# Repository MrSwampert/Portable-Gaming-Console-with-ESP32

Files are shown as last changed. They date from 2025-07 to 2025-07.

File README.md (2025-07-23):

# ArcadESP - The Open-Source Retro Gaming Handheld
Portable Gaming Console with ESP32-WROVER, TFT Display, and MicroSD Storage.

# Summary:

ArcadESP is an open-source, portable, retro video game console. Its main utility is to emulate games from classic consoles (such as the NES) using an ESP32 microcontroller, which is a very cheap and powerful chip. The main goal of the project is to leave it as a development board, which allows programming it for more functions.

# Description:
The circuit is centered on an ESP32-WROVER-IE microcontroller. The main power supply for the system is 3.3V.
The design integrates several key peripherals for operation. It includes a TFT screen for graphics display, managed through multiple GPIO connections of the microcontroller. For user input, the system features a series of buttons, including direction controls (up, down, left, right), action buttons (Start, Select, A, B, L, R), and menu buttons, which connect to a PCF8574 I/O port expander.
Data storage is handled through a MicroSD card slot with push-out functionality, allowing the reading and writing of information. Additionally, the circuit incorporates an auto-reset section for the microcontroller. Test points (TP1, TP2, TP3, TP4) are also included for monitoring key voltages such as V_USB, V_BATT and 3.3V.

# Features:
**Processing Core:** **ESP32-WROVER-IE** module with a dual-core CPU, Wi-Fi, Bluetooth, and integrated PSRAM.

**Connectivity & Power:** **USB-B port** for power and programming via an onboard **CH340 USB-to-UART** controller.

**Power Management:** Includes an **LTC4054** Li-Ion battery charger and an **MIC5219 LDO regulator** for a stable 3.3V supply.

**Audio Subsystem:** Features an I2S Stereo DAC (**UDA1334ATS**), a **PAM8403 Class-D amplifier**, and a **3.5mm audio jack** output.

**User Interface:** **TFT color display** for visual output, accompanied by user input buttons and a status LED.

**External Storage:** **Micro SD card slot** for expandable data and media storage.

**I/O Expansion:** **PCF8574 I/O expander** to provide additional digital pins over the I2C bus.

# Applications: 
-	Retro Emulation Console (Main Application)
-	Portable Media Player
-	IoT Device and Control Tool
-	Development and Learning Platform (All in One)

**Entertainment:** Play classic video games on a device you built yourself.
 
**Education:** It's a fantastic tool for learning about electronics, microcontroller programming (in the Arduino IDE), and how software emulation works.
 
**Personal Project (DIY):** It offers the satisfaction of building a functional gadget from scratch, with a very low cost (less than $20, according to similar projects).

# In Terms of Gaming:

Releases are here **https://github.com/retro-esp32/RetroESP32/releases**

It includes 11, YES eleven emulators.

 - Nintendo Entertainment System (NES)
 - Nintendo Game Boy (GB)
 - Nintendo Game Boy Color (GBC)
 - Sega Master System
 - Sega Game Gear
 - Colecovision
 - Sinclair Zx Spectrum 48k
 - Atari 2600
 - Atari 7800
 - Atari Lynx
 - PC Engine

# Sector Focus:
The project is clearly focused on the maker or DIY sector. The target audience are:
 
**Students and Electronics Hobbyists:** People who want to put their hardware and software knowledge into practice.

**Retro Gaming Enthusiasts:** Nostalgic gamers who would enjoy not only playing, but also building their own console.
 
**Programmers and Developers:** Those interested in developing software for embedded systems and optimizing code for hardware with limited resources. (For example, **PICO-8** is a virtual machine that emulates a video game console. While it is impossible to replicate with **ESP32**, there are alternatives such as **Fake-8**, which is the best open source way to run **PICO-8** games on unsupported platforms).

This is not a product for the end consumer looking for an **“out-of-the-box”** console, but for someone who values the process of creation and customization.

The differential value of ArcadESP is its low cost, the use of the versatile ESP32 and its open-source nature, which invites a community to modify, improve and share their own versions.

# Power Budget:
Power Budget

# Block Diagram:
Block Diagram

# Schematic
Schematic_v1_page-0001

Schematic_v1_page-0002

# 3D Model:




# References:

Pebri, “GitHub - pebri86/esplay_micro_hardware: Micro version of esplay hardware, ESP32 based gaming console,” GitHub. **https://github.com/pebri86/esplay_micro_hardware**

“ESPLay Micro V2,” Handheld ESP32 Game Console | Makerfabs. **https://www.makerfabs.com/esplay-micro-v2.html** 

Pebri, “GitHub - pebri86/esplay-retro-emulation: Retro Emulation Collection for ESPlay Hardware, an ESP32 based game console,” GitHub. **https://github.com/pebri86/esplay-retro-emulation**

Pebri, “GitHub - pebri86/esplay-micro-firmware-collections: Firmware files collections (*.fw) for ESPlay Micro,” GitHub. **https://github.com/pebri86/esplay-micro-firmware-collections**

Jtothebell, “GitHub - jtothebell/fake-08: A Pico-8 player/emulator for console homebrew,” GitHub. **https://github.com/jtothebell/fake-08**

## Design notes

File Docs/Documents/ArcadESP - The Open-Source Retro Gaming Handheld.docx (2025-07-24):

Portable Gaming Console with ESP32-WROVER, TFT Display, and MicroSD Storage

Santiago Galeano Castaño Date: 07/23/2025

Summary

ArcadESP is an open-source, portable, retro video game console. Its main utility is to emulate games from classic consoles (such as the NES) using an ESP32 WROVER IE microcontroller, which is a very cheap and powerful chip. The main goal of the project is to leave it as a development board, which allows programming it for more functions.

3D View Reference:

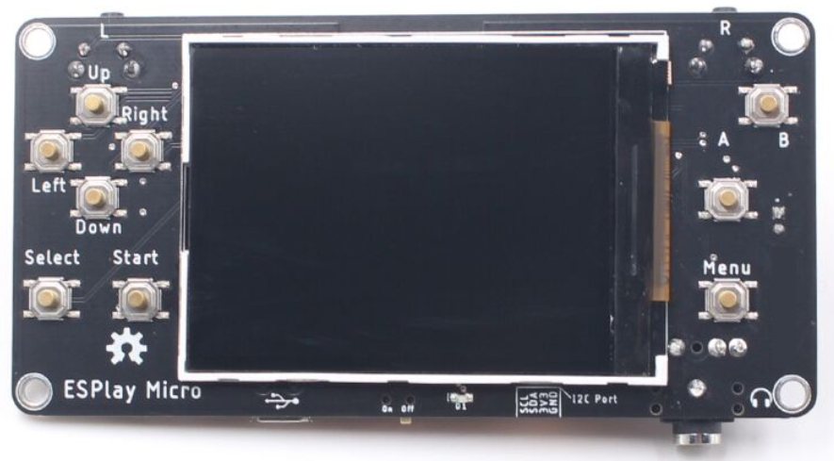
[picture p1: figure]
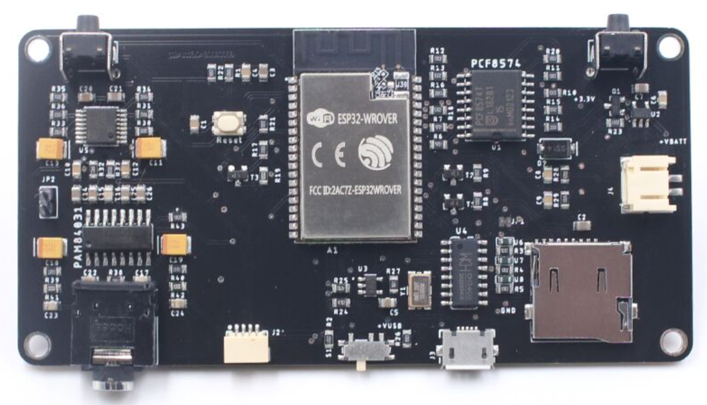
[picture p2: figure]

ArcadESP: The Open-Source Retro Gaming Handheld

Description:

The circuit is centered on an ESP32-WROVER-I microcontroller. The main power supply for the system is 3.3V.

The design integrates several key peripherals for operation. It includes a TFT screen for graphics display, managed through multiple GPIO connections of the microcontroller. For user input, the system features a series of buttons, including direction controls (up, down, left, right), action buttons (Start, Select, A, B), and menu buttons, which connect to a PCF8574 I/O port expander.

Data storage is handled through a MicroSD card slot with push-out functionality, allowing the reading and writing of information. Additionally, the circuit incorporates an auto-reset section for the microcontroller. Test points (TP1, TP2, TP3, TP4) are also included for monitoring key voltages such as V_USB, V_BATT and 3.3V.

Resources:

USB-B (https://lcsc.com/datasheet/lcsc_datasheet_2110151630_XKB-Connection-U-E-M1SS-Y-1_C319151.pdf) | Power and data connector.
LTC4054 (https://lcsc.com/datasheet/lcsc_datasheet_2409272231_NATLINEAR-LN2054Y42AMR_C141406.pdf) | Integrated circuit for battery charging.
MIC5219 3.3v Regulator (https://lcsc.com/datasheet/lcsc_datasheet_2410121904_MICROCHIP-MIC5219-3-3YM5-TR_C29613.pdf) | Regulates and stabilizes the voltage to 3.3V.
ESP32 WROVER-I (https://lcsc.com/datasheet/lcsc_datasheet_2411121102_ESPRESSIF-ESP32-WROVER-IE-N8R8_C701351.pdf) | The main microcontroller (the brain).
CH340 (https://lcsc.com/datasheet/lcsc_datasheet_2506051505_WCH-CH340G_C14267.pdf) | USB to serial converter for programming.
BUTTONS (https://lcsc.com/datasheet/lcsc_datasheet_2304140030_XKB-Connection-TS-1187A-C-C-B_C318889.pdf) | Buttons for user interaction.
PCF8574 I/O Expander (https://lcsc.com/datasheet/lcsc_datasheet_2504101957_HGSEMI-PCF8574T-TR_C2987288.pdf) | Expands input/output pins for the buttons.
TFT Display (https://cdn-shop.adafruit.com/datasheets/ILI9341.pdf) | Screen for visual output.
Micro SD Card (https://lcsc.com/datasheet/lcsc_datasheet_1811082127_Korean-Hroparts-Elec-TF-01A_C91145.pdf) | Module for external storage.
Audio DAC UDA1334ATS (https://www.nxp.com/docs/en/data-sheet/UDA1334ATS.pdf) | Converts digital audio to analog.
Amplifier PAM8403 (https://lcsc.com/datasheet/lcsc_datasheet_2208041800_Slkor-SLKORMICRO-Elec--PAM8403_C5122557.pdf) | Amplifies the audio signal for output.
Jack 3.5mm (https://lcsc.com/datasheet/lcsc_datasheet_2409271733_Korean-Hroparts-Elec-PJ-611-5A_C128983.pdf) | Output connector for headphones or speakers.
LED Blue (https://lcsc.com/datasheet/lcsc_datasheet_2507101606_Hubei-KENTO-Elec-KT-0603B_C2288.pdf) | Visual status indicator light.

Features:

Processing Core: ESP32-WROVER-IE N8R8 module with a dual-core CPU, Wi-Fi, Bluetooth, and integrated PSRAM.

Connectivity & Power: USB-B port for power and programming via an onboard CH340 USB-to-UART controller.

Power Management: Includes an LTC4054 Li-Ion battery charger and an MIC5219 LDO regulator for a stable 3.3V supply.

Audio Subsystem: Features an I2S Stereo DAC (UDA1334ATS), a PAM8403 Class-D amplifier, and a 3.5mm audio jack output.

User Interface: TFT color display for visual output, accompanied by user input buttons and a status LED.

External Storage: Micro SD card slot for expandable data and media storage.

I/O Expansion: PCF8574 I/O expander to provide additional digital pins over the I2C bus.

Applications:

- Retro Emulation Console (Main Application)
- Portable Media Player
- IoT Device and Control Tool
- Development and Learning Platform (All in One)

Power Tree:

▶ Power Source (USB / Battery)

└───▶ Power Systems & Protections

│

├───▶ Charging Circuit (e.g., TP4056)

│ │

│ ├───> Charges the Li-Po Battery (3.7V)

│ │

│ └───> Status LEDs (Charging / Full)

│

└───▶ 3.3V Voltage Regulator

│

└───▶ Main Power Rail (3.3V)

│

├─▶ B. Processing & Storage

│ ├─ Microcontroller (ESP32)

│ └─ Storage (MicroSD Slot)

│

├─▶ C. Output (Display & Audio)

│ ├─ Display (TFT)

│ └─ Audio Output (DAC / Amp)

│

├─▶ D. Inputs & Controls

│ ├─ I/O Expander (I2C)

│ └─ Auto-Reset Circuit

└─▶ E. Debug & Programming

└─ USB to UART Interface

Input Source: Power originates from either a USB connection or a Li-Po Battery.

Charging & Protection: This input power feeds a charging circuit, which manages battery charging and provides a regulated output. This stage also powers the status LEDs.

Main Regulation: Power from the battery or charging circuit is routed to the 3.3V Voltage Regulator. This is the core of the power system, converting the variable battery voltage (typically 3.0V-4.2V) into a stable, constant 3.3V.

Distribution: The 3.3V rail distributes power to all active modules in the device: the microcontroller, display, audio circuitry, SD card slot, I/O expander, and the programming interface.

Power Budget:

The system can be powered by a USB connection or a Li-Po battery. The input power goes through a protection and charging circuit. A central 3.3V voltage regulator then takes this power and supplies a stable 3.3v to all the main components. These components include the ESP32 microcontroller, the TFT display, the audio output, the MicroSD slot, and the input/control circuits.

Typical Use: The device draws 423 mA (2.12 W) from the 5V USB source for normal operation.

Maximum Use: Under heavy load (like using Wi-Fi), the draw spikes to 1.11 A (5.55 W) from the 5V USB source.

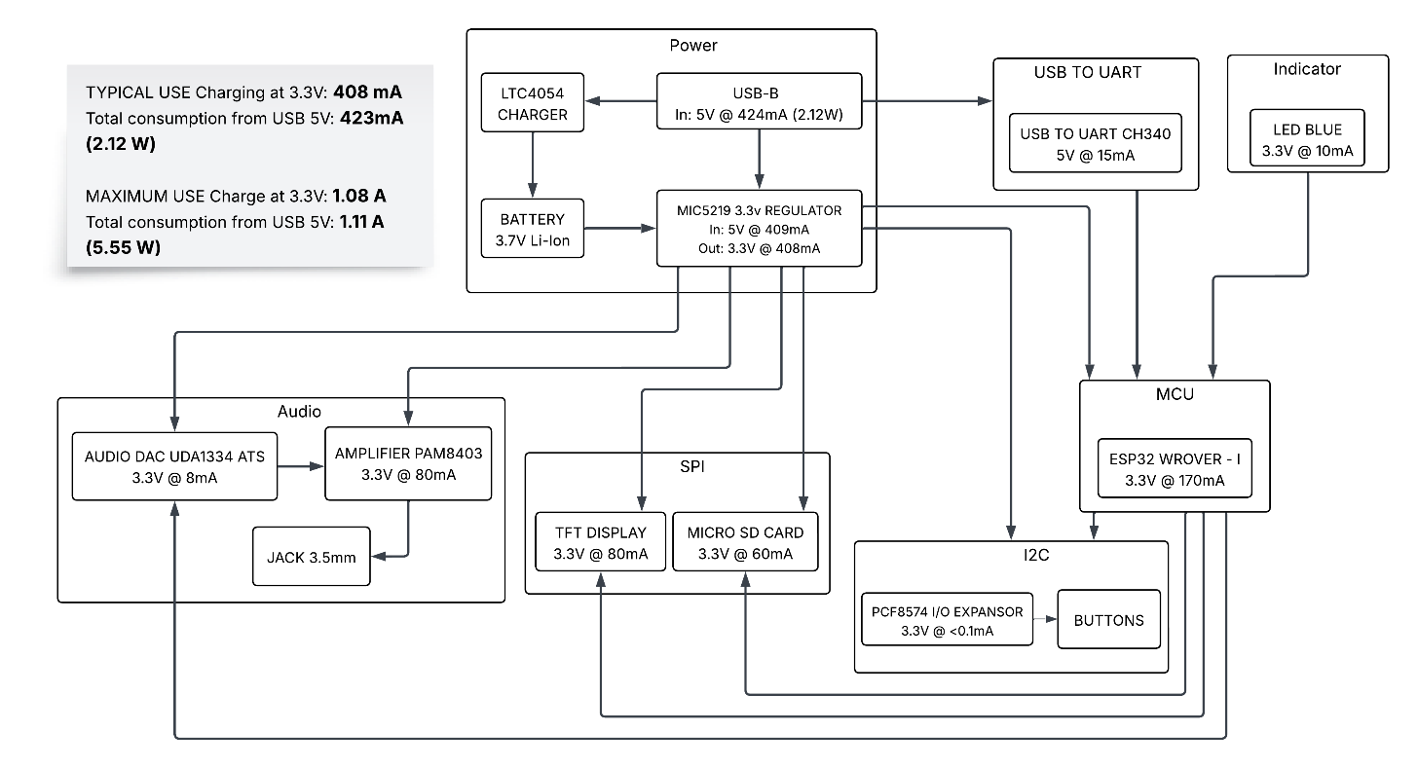
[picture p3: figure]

Block Diagram:

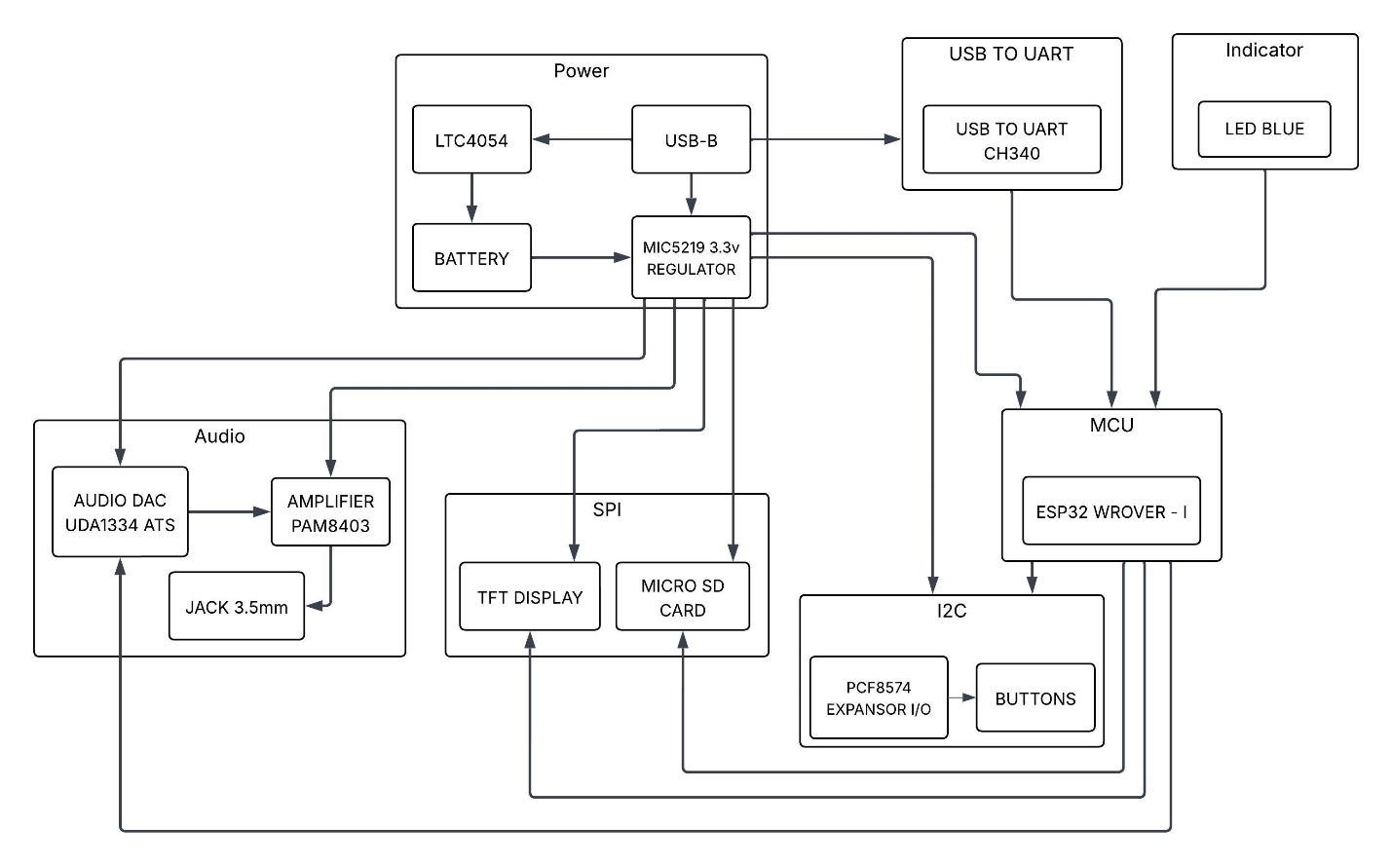
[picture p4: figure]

Schematic:

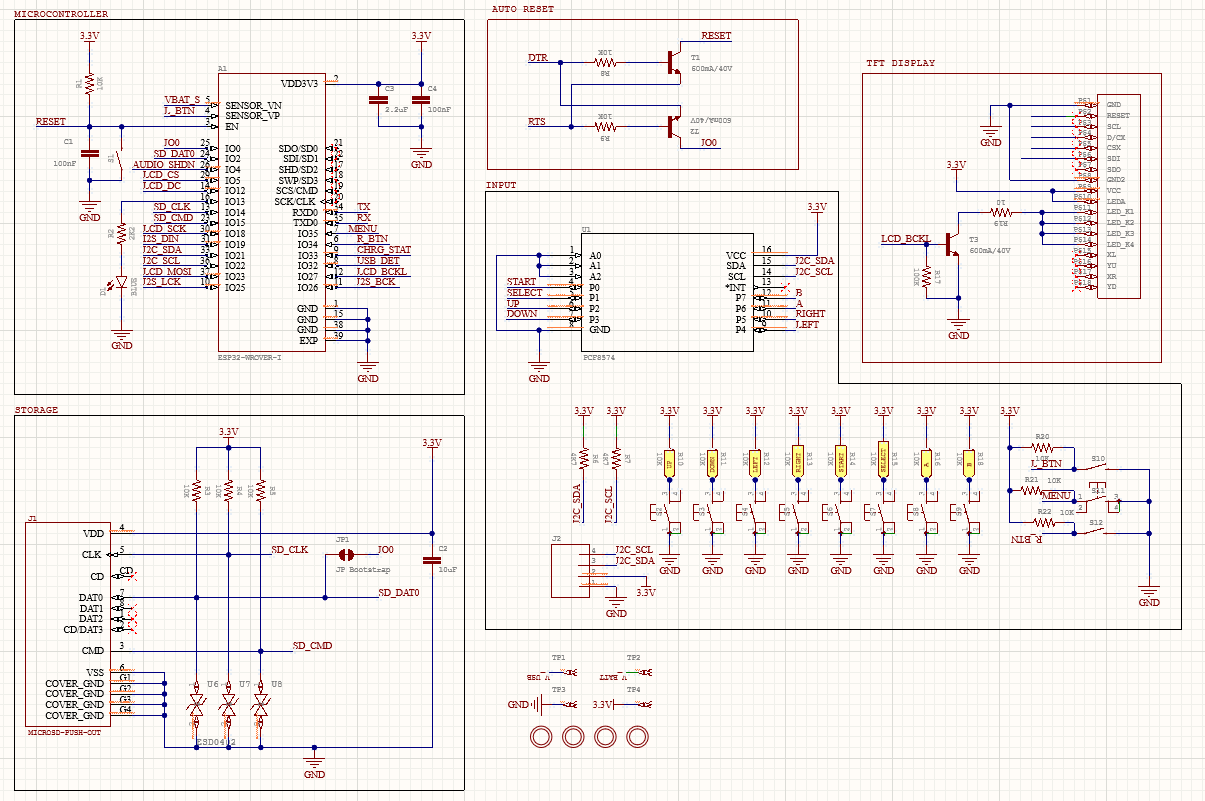
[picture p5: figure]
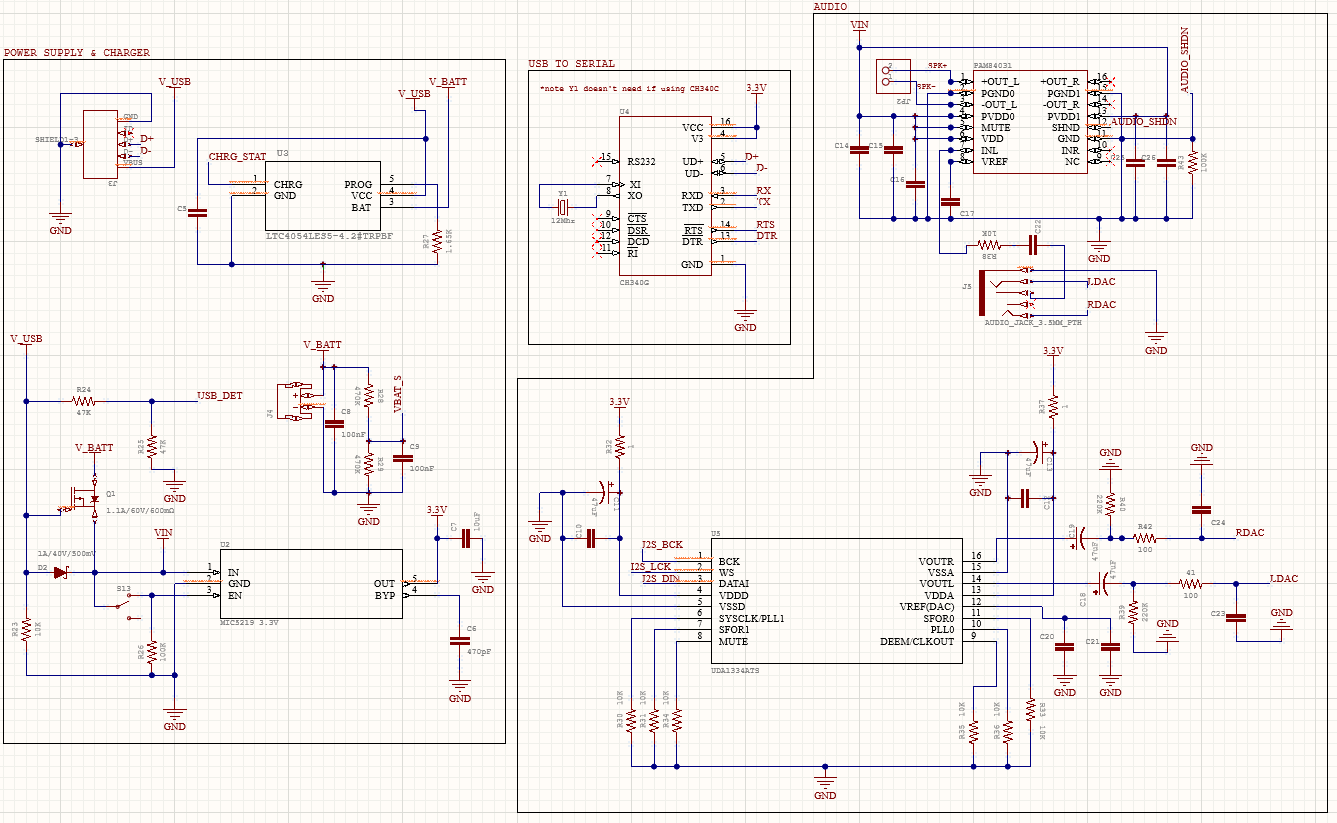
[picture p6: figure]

3D Model Without Components:

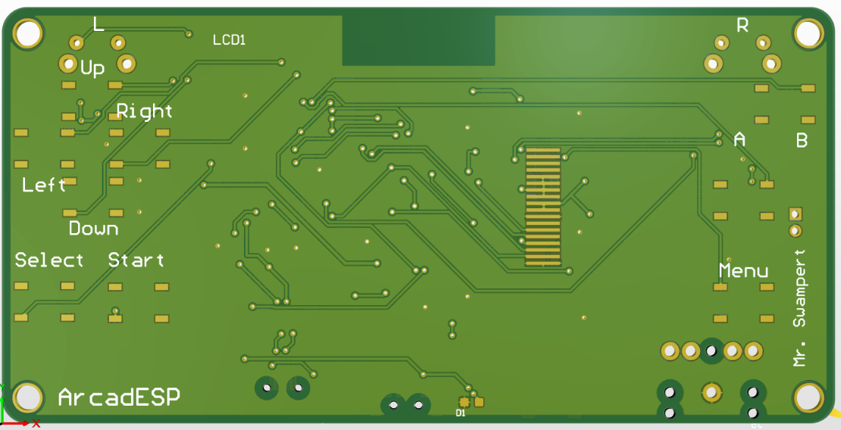
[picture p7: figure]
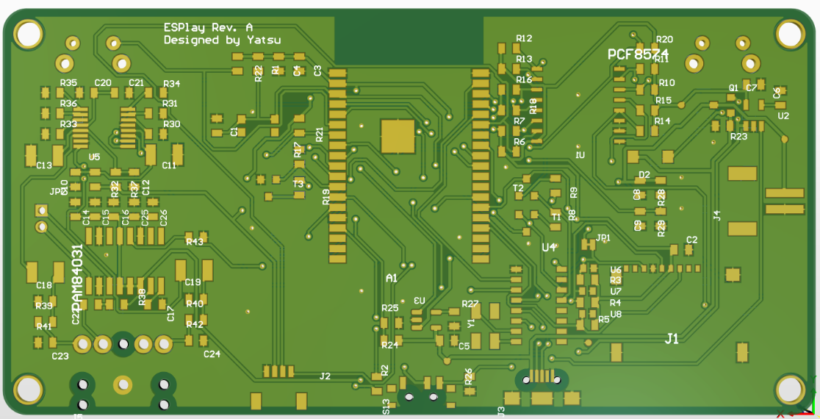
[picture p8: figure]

The PCB is similar, but there are differences since the original idea is that it can be used as a development board.

Temperature:

Component | Category | Operating Temperature Range | Additional Notes
LTC4054 | Battery Charger | 0°C to 70°C (Guaranteed Performance) | The operating range extends from -40°C to 85°C. It has a thermal protection feature that reduces charging current if the internal temperature exceeds 120°C.
MIC5219 | Voltage Regulator | -40°C to 125°C | This 3.3V regulator has a wide operating range, suitable for various environmental conditions.
ESP32 WROVER-I | MCU | -40°C to 85°C | Most ESP32-WROVER models operate in this range, making them robust for embedded applications.
PAM8403 | Audio Amplifier | -40°C to 85°C | Includes over-temperature protection that shuts down the device if the internal temperature reaches 140°C.
CH340 | USB to UART | -40°C to 85°C | This is the standard range for most variants of this converter chip.
PCF8574 | I/O Expander | -40°C to 85°C | This component for input/output port expansion operates in a standard industrial range.
UDA1334A | Audio DAC | -20°C to 85°C | The digital-to-analog audio converter has a slightly more restricted operating range at the lower end compared to other components.
TFT Display | Display | Generally, 0°C to 50°C (Typical) | Exact ranges can vary depending on the manufacturer, but this is a common range for consumer TFT displays. Operation outside this range can affect visibility and lifespan.
Micro SD Card | Storage | -25°C to 85°C (Typical for Industrial Grade) | Consumer-grade cards may have a more limited range (e.g., 0°C to 70°C). The exact range depends on the specification of the card used.
Blue LED | Indicator | -40°C to 85°C (Typical) | Light-emitting diodes (LEDs) typically have a very wide operating range.

In Terms of Gaming:

It includes 11, YES eleven emulators, like NES, Game Boy, Game Boy Color and More.

Sector Focus:

The project is clearly focused on the maker or DIY sector. The target audience are:

Students and Electronics Hobbyists: People who want to put their hardware and software knowledge into practice.

Retro Gaming Enthusiasts: Nostalgic gamers who would enjoy not only playing but also building their own console.

Programmers and Developers: Those interested in developing software for embedded systems and optimizing code for hardware with limited resources. (For example, PICO-8 is a virtual machine that emulates a video game console. While it is impossible to replicate with ESP32, there are alternatives such as Fake-8, which is the best open-source way to run PICO-8 games on unsupported platforms).

This is not a product for the end consumer looking for an “out-of-the-box” console, but for someone who values the process of creation and customization.

The differential value of ArcadESP is its low cost, the versatile ESP32 and its open-source nature, which invites a community to modify, improve and share their own versions.

References:

Pebri, “GitHub - pebri86/esplay_micro_hardware: Micro version of esplay hardware, ESP32 based gaming console,” GitHub. https://github.com/pebri86/esplay_micro_hardware

“ESPLay Micro V2,” Handheld ESP32 Game Console | Makerfabs. https://www.makerfabs.com/esplay-micro-v2.html

Link to the repository where the files are hosted:

https://github.com/MrSwampert/Portable-Gaming-Console-with-ESP32

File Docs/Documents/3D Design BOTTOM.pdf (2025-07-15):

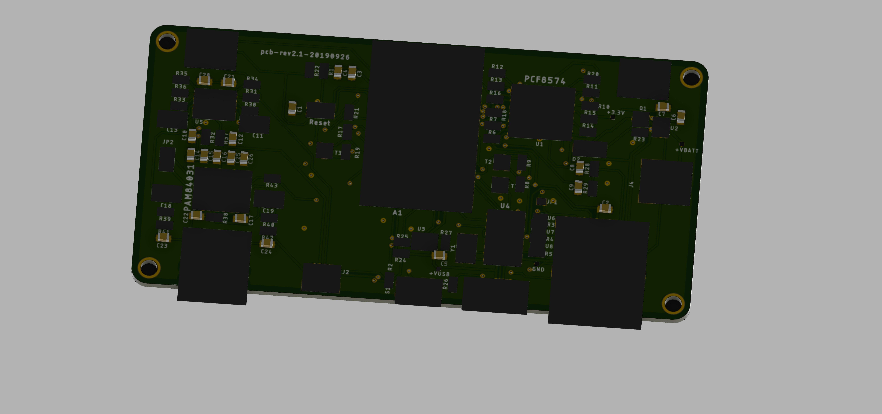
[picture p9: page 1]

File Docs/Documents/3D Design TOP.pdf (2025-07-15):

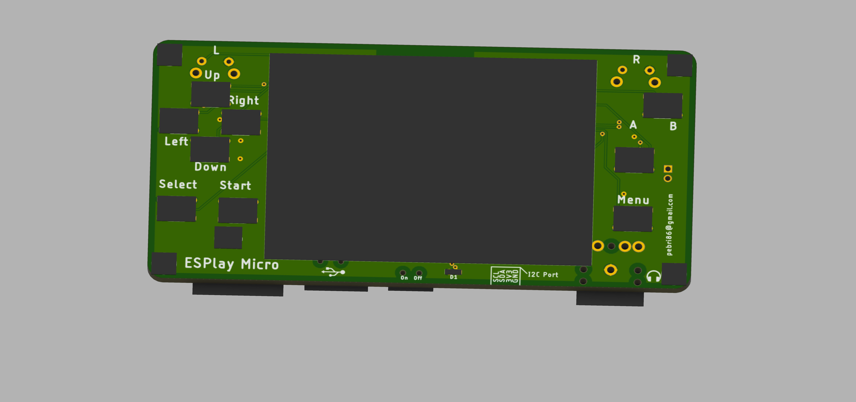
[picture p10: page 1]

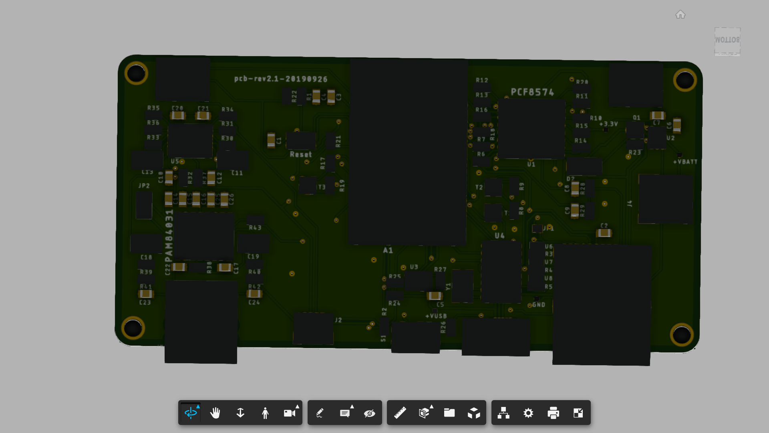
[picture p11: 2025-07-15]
Docs/Images/BOTTOM.png

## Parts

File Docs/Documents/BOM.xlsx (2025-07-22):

Name | Description | Package | Designator | Quantity | Links | LCSC Number Part | Unit Price
ESP32-WROVER-I | Module: combo; GPIO, I2C x2, I2S x2, SDIO, SPI x3, UART x3; U.FL | XCVR_ESP32-WROVER-I | A1 | 1 | https://lcsc.com/product-detail/WiFi-Modules_Espressif-Systems-ESP32-WROVER-IE-N8R8_C701351.html | C701351 | $4.53
100nF | 2.2ÂµF ceramic capacitors A capacitor is a passive two-terminal electrical component used to store electrical energy temporarily in an electric field. | O805 | C1, C4, C8, C9, C10, C12, C20 | 7 | https://lcsc.com/product-detail/Multilayer-Ceramic-Capacitors-MLCC-SMD-SMT_Walsin-0805B104K500CT_C83055.html | C83055 | $0.05
10uF | 2.2ÂµF ceramic capacitors A capacitor is a passive two-terminal electrical component used to store electrical energy temporarily in an electric field. | O805 | C2, C7, C14, C21, C26 | 5 | https://lcsc.com/product-detail/Multilayer-Ceramic-Capacitors-MLCC-SMD-SMT_FH-0805X106M250NT_C669099.html | C669099 | $0.82
2.2uF | 2.2ÂµF ceramic capacitors A capacitor is a passive two-terminal electrical component used to store electrical energy temporarily in an electric field. | O805 | C3 | 1 | https://lcsc.com/product-detail/Multilayer-Ceramic-Capacitors-MLCC-SMD-SMT_Samsung-Electro-Mechanics-CL21A106KAYNNNE_C15850.html | C15850 | $0.22
1uF | 2.2ÂµF ceramic capacitors A capacitor is a passive two-terminal electrical component used to store electrical energy temporarily in an electric field. | O805 | C5, C15, C25 | 3 | https://lcsc.com/product-detail/Multilayer-Ceramic-Capacitors-MLCC-SMD-SMT_YAGEO-CC0805KKX7R8BB105_C91186.html | C91186 | $0.49
470pF | 2.2ÂµF ceramic capacitors A capacitor is a passive two-terminal electrical component used to store electrical energy temporarily in an electric field. | O805 | C6 | 1 | https://lcsc.com/product-detail/Multilayer-Ceramic-Capacitors-MLCC-SMD-SMT_CCTC-TCC0805X7R471K500DT_C309041.html | C309041 | $0.43
47uF | 47UF-POLAR-EIA3528-10V-10% | EIA3528 | C11, C13, C18, C19 | 4 | https://lcsc.com/product-detail/Tantalum-Capacitors_Kyocera-AVX-TAJB476K010RNJ_C22036.html | C22036 | $0.67
10nF | 2.2ÂµF ceramic capacitors A capacitor is a passive two-terminal electrical component used to store electrical energy temporarily in an electric field. | O805 | C16, C17, C23, C24 | 4 | https://lcsc.com/product-detail/Multilayer-Ceramic-Capacitors-MLCC-SMD-SMT_YAGEO-CC0805KRX7R9BB103_C83170.html | C83170 | $0.46
220nF | 2.2ÂµF ceramic capacitors A capacitor is a passive two-terminal electrical component used to store electrical energy temporarily in an electric field. | O805 | C22 | 1 | https://lcsc.com/product-detail/Multilayer-Ceramic-Capacitors-MLCC-SMD-SMT_IHHEC-C0805X224K050T_C915839.html | C915839 | $0.61
BLUE | LED-BLUE0603 | LED-0603 | D1 | 1 | https://lcsc.com/product-detail/LED-Indication-Discrete_Hubei-KENTO-Elec-KT-0603B_C2288.html | C2288 | $0.48
1A/40V/500mV | DIODE-SCHOTTKY-SS14 | SMA-DIODE | D2 | 1 | https://lcsc.com/product-detail/Schottky-Diodes_DIYI-Elec-Tech-SS14_C84170.html | C84170 | $0.20
MICROBUILDER_MOUNTINGHOLE3.0THIN | Mounting Hole For #2 screws (0.086"/2.18mm width, 0.094"/2.4mm hole) use 2.5mm | MICROBUILDER_MOUNTINGHOLE_3.0_PLATEDTHIN | H1, H2, H3, H4 | 4
MICROSD-PUSH-OUT | T-Flash Push-Out Micro SD Card Reader 14.75mm x 14.5mm SMD with external pins | MICROSD-PUSH-OUT | J1 | 1 | https://lcsc.com/product-detail/SD-Card-Memory-Card-Connector_Korean-Hroparts-Elec-TF-01A_C91145.html | C91145 | $0.86
QWIIC_CONNECTORJS-1MM | SparkFun I2C Standard Qwiic Connector An SMD 1mm pitch JST connector makes it easy and quick (get it? Qwiic?) to connect I2C devices to each other. The Qwiic system enables fast and solderless connection between popular platforms and various sensors and actuators. We carry 200mm, 100mm, 50mm, and breadboard friendly Qwiic cables. We also offer 10 pcs strips the SMD connectors. | 1X04_1MM_RA | J2 | 1 | https://lcsc.com/product-detail/Wire-To-Board-Connector_JST-BM04B-SRSS-TB-LF-SN_C160390.html | C160390 | $0.93
USB_MICRO-B_FEMALE-SMT | USB_MICRO-B_FEMALE-SMT | USB-B-MICRO-SMD | J3 | 1 | https://lcsc.com/product-detail/USB-Connectors_XKB-Connection-U-E-M1SS-Y-1_C319151.html | C319151 | $1.09
JST_2MM_MALE | JST_2MM_MALE | JST-2-SMD | J4 | 1 | https://lcsc.com/product-detail/Wire-To-Board-Connector_JST-B4B-PH-SM4-TB-LF-SN_C160354.html | C160354 | $0.81
AUDIO_JACK_3.5MM_PTH | AUDIO_JACK_3.5MM_PTH | AUDIO-JACK | J5 | 1 | https://lcsc.com/product-detail/Audio-Connectors_Korean-Hroparts-Elec-PJ-611-5A_C128983.html | C128983 | $0.90
JP Bootstrap | JUMPER-SMT_2_NC_TRACE_NO-SILK | SMT-JUMPER_2_NC_TRACE_NO-SILK | JP1 | 1
PINHD-1X2_2.00 | PINHD-1X2_2.00 | 1X02M | JP2 | 1 | https://lcsc.com/product-detail/Wire-To-Board-Connector_XKB-Connection-X8821WV-02-N0SN_C2884141.html | C2884141 | $0.73
ILI9341-2.4 | ILI9341-2.4 | ILI9341-2.4 | LCD1 | 1 | https://articulo.mercadolibre.com.co/MCO-548627635-pantalla-tactil-lcd-tft-24-pulgadas-240x320-spi-ili9341-sd-_JM |  | $7.90
PAM8403 | Dual channel audio amplifier IC - PAM8403 | SOP-16 | PAM84031 | 1 | https://lcsc.com/product-detail/Audio-Amplifiers_Slkor-SLKORMICRO-Elec-PAM8403_C5122557.html | C5122557 | $1.32
1.1A/60V/600mΩ | MOSFET_PCH-SI2309DS | SOT23-3 | Q1 | 1 | https://lcsc.com/product-detail/MOSFETs_AOS-AO3401A_C15127.html | C15127 | $0.64
10K | 0.22OHM-0805-1/4W-1% | O805 | R1, R3, R4, R5, R8, R9, R10, R11, R12, R13, R14, R15, R16, R18, R20, R21, R22, R23 | 18 | https://lcsc.com/product-detail/Chip-Resistor-Surface-Mount_PANASONIC-ERA6VEB1002V_C490804.html | C490804 | $0.47
2K2 | 0.22Î© resistor A resistor is a passive two-terminal electrical component that implements electrical resistance as a circuit element. Resistors act to reduce current flow, and, at the same time, act to lower voltage levels within circuits. - Wikipedia | O805 | R2 | 1 | https://lcsc.com/product-detail/Chip-Resistor-Surface-Mount_YAGEO-AC0805FR-7W2K2L_C5545398.html | C5545398 | $0.79
4K7 | 0.22Î© resistor A resistor is a passive two-terminal electrical component that implements electrical resistance as a circuit element. Resistors act to reduce current flow, and, at the same time, act to lower voltage levels within circuits. - Wikipedia | O805 | R6, R7 | 2 | https://lcsc.com/product-detail/Chip-Resistor-Surface-Mount_YAGEO-AC0805FR-7W4K7L_C6457904.html | C6457904 | $0.40
100K | 0.22Î© resistor A resistor is a passive two-terminal electrical component that implements electrical resistance as a circuit element. Resistors act to reduce current flow, and, at the same time, act to lower voltage levels within circuits. - Wikipedia | O805 | R17, R26 | 2 | https://lcsc.com/product-detail/Chip-Resistor-Surface-Mount_VISHAY-RCC0805100KFKEA_C1859593.html | C1859593 | $0.52
10 | 0.22Î© resistor A resistor is a passive two-terminal electrical component that implements electrical resistance as a circuit element. Resistors act to reduce current flow, and, at the same time, act to lower voltage levels within circuits. - Wikipedia | O805 | R19 | 1 | https://lcsc.com/product-detail/Chip-Resistor-Surface-Mount_YAGEO-AC0805JR-7W10RL_C728003.html | C728003 | $0.53
47K | 0.22Î© resistor A resistor is a passive two-terminal electrical component that implements electrical resistance as a circuit element. Resistors act to reduce current flow, and, at the same time, act to lower voltage levels within circuits. - Wikipedia | O805 | R24, R25 | 2 | https://lcsc.com/product-detail/Chip-Resistor-Surface-Mount_KOA-Speer-Elec-RK73H2ATTD4702F_C160080.html | C160080 | $0.72
1.65K | 0.3OHM-0805-1/8W-1% | O805 | R27 | 1 | https://lcsc.com/product-detail/Chip-Resistor-Surface-Mount_FOJAN-FRC0805F1651TS_C2933334.html | C2933334 | $0.13
470K | 0.22OHM-0805-1/4W-1% | O805 | R28, R29 | 2 | https://lcsc.com/product-detail/Chip-Resistor-Surface-Mount_KOA-Speer-Elec-RK73H2ATTD4703F_C276230.html | C276230 | $0.50
10K | 0.3OHM-0805-1/8W-1% | O805 | R30, R31, R33, R34, R35, R36, R38 | 7 | https://lcsc.com/product-detail/Chip-Resistor-Surface-Mount_YAGEO-RC0805FR-0710KL_C84376.html | C84376 | $0.19
1 | 0.3OHM-0805-1/8W-1% | O805 | R32, R37 | 2 | https://lcsc.com/product-detail/Chip-Resistor-Surface-Mount_FOJAN-FRC0805J1R0TS_C2930253.html | C2930253 | $0.14
220K | 0.3OHM-0805-1/8W-1% | O805 | R39, R40 | 2 | https://lcsc.com/product-detail/Chip-Resistor-Surface-Mount_YAGEO-RV0805FR-07220KL_C873358.html | C873358 | $0.51
100 | 0.3OHM-0805-1/8W-1% | O805 | R41, R42 | 2 | https://lcsc.com/product-detail/Chip-Resistor-Surface-Mount_UNI-ROYAL-0805W8F1000T5E_C17408.html | C17408 | $0.19
100K | 0.3OHM-0805-1/8W-1% | O805 | R43 | 1 | https://lcsc.com/product-detail/Chip-Resistor-Surface-Mount_ROHM-KTR10EZPF1003_C3014170.html | C3014170 | $0.69
RST | MOMENTARY-SWITCH-SPST-SMD-4.6X2.8MM | TACTILE_SWITCH_SMD_4.6X2.8MM | S1 | 1
MOMENTARY-SWITCH-SPST-2-SMD-5.2MM | MOMENTARY-SWITCH-SPST-2-SMD-5.2MM | TACTILE_SWITCH_SMD_5.2MM | S2, S3, S4, S5, S6, S7, S8, S9, S11 | 9 | https://www.digikey.com/en/products/detail/e-switch/TL3145BF180QJ/12749785 | TL3145BF180QJ | $3.78
L | MOMENTARY-SWITCH-SPST-PTH-RIGHT-ANGLE-KIT | TACTILE_SWITCH_PTH_RIGHT_ANGLE_KIT | S10 | 1 | https://lcsc.com/product-detail/Tactile-Switches_XKB-Connection-TS-1187A-C-C-B_C318889.html | C318889 | $0.61
R | MOMENTARY-SWITCH-SPST-PTH-RIGHT-ANGLE-KIT | TACTILE_SWITCH_PTH_RIGHT_ANGLE_KIT | S12 | 1 | https://lcsc.com/product-detail/Tactile-Switches_XKB-Connection-TS-1187A-C-C-B_C318889.html | C318889
SWITCH-SPDT-SMD-RIGHT-ANGLE | SWITCH-SPDT-SMD-RIGHT-ANGLE | SWITCH_SPST_SMD_A | S13 | 1
600mA/40V | TRANS_NPN-MMBT2222AL | SOT23-3 | T1, T2, T3 | 3 | https://lcsc.com/product-detail/Bipolar-BJT_MDD-Microdiode-Semiconductor-MMBT2222A_C364315.html | C364315 | $0.74
TEST-POINT3 | TEST-POINT3 | PAD.03X.03 | TP1, TP2, TP3, TP4 | 4
PCF8574 | PCF8574 | SO16 | U1 | 1 | https://lcsc.com/product-detail/I-O-Expanders_HGSEMI-PCF8574T-TR_C2987288.html | C2987288 | $0.79
MIC5219 3.3V | V_REG_MIC52193.3V | SOT23-5 | U2 | 1 | https://lcsc.com/product-detail/Voltage-Regulators-Linear-Low-Drop-Out-LDO-Regulators_Microchip-Tech-MIC5219-3-3YM5-TR_C29613.html | C29613 | $0.45
LTC4054LES5-4.2#TRPBF | LTC4054LES5-4.2#TRPB | SOT95P280X100-5N | U3 | 1 | https://lcsc.com/product-detail/Battery-Management_NATLINEAR-LN2054Y42AMR_C141406.html | C141406 | $0.61
CH340G | CH340GSMD | SO016 | U4 | 1 | https://lcsc.com/product-detail/USB-Converters_WCH-Jiangsu-Qin-Heng-CH340G_C14267.html | C14267 | $0.51
UDA1334ATS | MICROBUILDER_AUDIO_I2S_UDA1334"" | MICROBUILDER_SSOP16_4.4MM | U5 | 1 | https://www.amazon.com/-/es/UDA1334ATS-SSOP-16-conversi%C3%B3n-anal%C3%B3gico-digital/dp/B08PMC6HCH |  | $10.54
ESD0402 | ESD0402 | ESD0402 | U6, U7, U8 | 3 | https://lcsc.com/product-detail/ESD-and-Surge-Protection-TVS-ESD_DOWO-PESD0402V05_C19626254.html | C19626254 | $0.58
12Mhz | CRYSTALSMD-5X3.2-4PAD | CRYSTAL-SMD-5X3.2-4PAD | Y1 | 1 | https://lcsc.com/product-detail/Crystals_YXC-Crystal-Oscillators-X322516MLB4SI_C13738.html | C13738 | $0.66
 |  |  |  |  |  | Subtotal | $49.19
 | LTC4054LES5-4.2#TRPBF |  |  |  | https://www.digikey.com/en/products/detail/linear-technology-analog-devices/LTC4054LES5-4.2-TRPBF/1888452 |  | $6.14
 | LTC4054LES5-4.2#TRPBF |  |  |  | https://lcsc.com/product-detail/Battery-Management_ADI-LTC4054LES5-4-2-TRPBF_C462691.html | C462691 | $6.08
UDA1334ATS | Alternativa para el chip. Sería desoldarlo del módulo e integrarlo en la placa |  |  |  | https://www.adafruit.com/product/3678 |  | $6.95

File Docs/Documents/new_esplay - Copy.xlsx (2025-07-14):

Name | Description | Designator | Quantity
ESP32-WROVER-I | Module: combo; GPIO, I2C x2, I2S x2, SDIO, SPI x3, UART x3; U.FL | A1 | 1 | https://lcsc.com/product-detail/WiFi-Modules_Espressif-Systems-ESP32-WROVER-IE-N8R8_C701351.html
100nF | 2.2ÂµF ceramic capacitors A capacitor is a passive two-terminal electrical component used to store electrical energy temporarily in an electric field. | C1, C4, C8, C9, C10, C12, C20 | 7
10uF | 2.2ÂµF ceramic capacitors A capacitor is a passive two-terminal electrical component used to store electrical energy temporarily in an electric field. | C2, C7, C14, C21, C26 | 5
2.2uF | 2.2ÂµF ceramic capacitors A capacitor is a passive two-terminal electrical component used to store electrical energy temporarily in an electric field. | C3 | 1
1uF | 2.2ÂµF ceramic capacitors A capacitor is a passive two-terminal electrical component used to store electrical energy temporarily in an electric field. | C5, C15, C25 | 3
470pF | 2.2ÂµF ceramic capacitors A capacitor is a passive two-terminal electrical component used to store electrical energy temporarily in an electric field. | C6 | 1
47uF | 47ÂµF polarized capacitors A capacitor is a passive two-terminal electrical component used to store electrical energy temporarily in an electric field. | C11, C13, C18, C19 | 4
10nF | 2.2ÂµF ceramic capacitors A capacitor is a passive two-terminal electrical component used to store electrical energy temporarily in an electric field. | C16, C17, C23, C24 | 4
220nF | 2.2ÂµF ceramic capacitors A capacitor is a passive two-terminal electrical component used to store electrical energy temporarily in an electric field. | C22 | 1
BLUE | Blue SMD LED Used in manufacturing of various products at SparkFun Packages: 0603 - SMD 0603 package [Product Link] 1206 - SMD1206 package [Product Link] SparkFun Products: ESP8266 Thing-Dev Board RedBoard | D1 | 1
1A/40V/500mV | Schottky diode A Schottky diode is a semiconductor diode which has a low forward voltage drop and a very fast switching action. | D2 | 1
MICROBUILDER_MOUNTINGHOLE3.0THIN | Mounting Hole For #2 screws (0.086"/2.18mm width, 0.094"/2.4mm hole) use 2.5mm | H1, H2, H3, H4 | 4
MICROSD-PUSH-OUT | T-Flash Push-Out Micro SD Card Reader 14.75mm x 14.5mm SMD with external pins | J1 | 1
QWIIC_CONNECTORJS-1MM | SparkFun I2C Standard Qwiic Connector An SMD 1mm pitch JST connector makes it easy and quick (get it? Qwiic?) to connect I2C devices to each other. The Qwiic system enables fast and solderless connection between popular platforms and various sensors and actuators. We carry 200mm, 100mm, 50mm, and breadboard friendly Qwiic cables. We also offer 10 pcs strips the SMD connectors. | J2 | 1
USB_MICRO-B_FEMALE-SMT | USB Type Micro-B Connector Male/female and PTH/SMT variants SparkFun Products: SparkFun microB USB Breakout SparkFun USB microB Plug Breakout SparkFun ESP8266 Thing | J3 | 1
JST_2MM_MALE | JST 2MM MALE RA CONNECTOR Two pin, compact surface mount connector. Commonly used as a battery input connection point. We really like the solid locking feeling and high current rating on these small connectors. We use these all the time as battery connectors. Mates to single-cell LiPo batteries. Here is the connector we sell at SparkFun: JST Right Angle Connector - White (PRT-08612) Datasheet It was used on these SparkFun products: SparkFun MOSFET Power Controller (PRT-11214) SparkFun Battery Babysitter - LiPo Battery Manager (PRT-13777) And many, many others that required a lipo battery connection. | J4 | 1
AUDIO_JACK_3.5MM_PTH | Audio Jack 3.5mm variants of PTH and SMT stereo audio jack with bypass switches. SparkFun Products: SparkFun SparkPunk Sound Kit - PTH MP3 Trigger -3.5mm SMD SparkFun PicoBoard- 2.5mm SMD | J5 | 1
JP Bootstrap | Normally closed trace jumper This jumper has a trace between two pads so it's normally closed (NC). Use a razor knife to open the connection. For best results follow the IPC guidelines for cutting traces: Cutout at least 0.063 mm (0.005 in). Remove all loose material to clean up the cut area. Seal the cut with an approved epoxy. Reapply solder to reclose the connection. | JP1 | 1
PINHD-1X2_2.00 | PIN HEADER | JP2 | 1
ILI9341-2.4 |  | LCD1 | 1
PAM8403 | Dual channel audio amplifier IC - PAM8403 | PAM84031 | 1
1.1A/60V/600mΩ | P-channel MOSFETs Voltage controlled devices that allow control of high current outputs. SparkFun Products: SparkFun ESP32 Thing SparkFun ESP8266 Thing | Q1 | 1
10K | 0.22Î© resistor A resistor is a passive two-terminal electrical component that implements electrical resistance as a circuit element. Resistors act to reduce current flow, and, at the same time, act to lower voltage levels within circuits. - Wikipedia | R1, R3, R4, R5, R8, R9, R10, R11, R12, R13, R14, R15, R16, R18, R20, R21, R22, R23 | 18
2K2 | 0.22Î© resistor A resistor is a passive two-terminal electrical component that implements electrical resistance as a circuit element. Resistors act to reduce current flow, and, at the same time, act to lower voltage levels within circuits. - Wikipedia | R2 | 1
4K7 | 0.22Î© resistor A resistor is a passive two-terminal electrical component that implements electrical resistance as a circuit element. Resistors act to reduce current flow, and, at the same time, act to lower voltage levels within circuits. - Wikipedia | R6, R7 | 2
100K | 0.22Î© resistor A resistor is a passive two-terminal electrical component that implements electrical resistance as a circuit element. Resistors act to reduce current flow, and, at the same time, act to lower voltage levels within circuits. - Wikipedia | R17, R26 | 2
10 | 0.22Î© resistor A resistor is a passive two-terminal electrical component that implements electrical resistance as a circuit element. Resistors act to reduce current flow, and, at the same time, act to lower voltage levels within circuits. - Wikipedia | R19 | 1
47K | 0.22Î© resistor A resistor is a passive two-terminal electrical component that implements electrical resistance as a circuit element. Resistors act to reduce current flow, and, at the same time, act to lower voltage levels within circuits. - Wikipedia | R24, R25 | 2
1.65K | 0.3Î© resistor A resistor is a passive two-terminal electrical component that implements electrical resistance as a circuit element. Resistors act to reduce current flow, and, at the same time, act to lower voltage levels within circuits. - Wikipedia | R27 | 1
470K | 0.22Î© resistor A resistor is a passive two-terminal electrical component that implements electrical resistance as a circuit element. Resistors act to reduce current flow, and, at the same time, act to lower voltage levels within circuits. - Wikipedia | R28, R29 | 2
10K | 0.3Î© resistor A resistor is a passive two-terminal electrical component that implements electrical resistance as a circuit element. Resistors act to reduce current flow, and, at the same time, act to lower voltage levels within circuits. - Wikipedia | R30, R31, R33, R34, R35, R36, R38 | 7
1 | 0.3Î© resistor A resistor is a passive two-terminal electrical component that implements electrical resistance as a circuit element. Resistors act to reduce current flow, and, at the same time, act to lower voltage levels within circuits. - Wikipedia | R32, R37 | 2
220K | 0.3Î© resistor A resistor is a passive two-terminal electrical component that implements electrical resistance as a circuit element. Resistors act to reduce current flow, and, at the same time, act to lower voltage levels within circuits. - Wikipedia | R39, R40 | 2
100 | 0.3Î© resistor A resistor is a passive two-terminal electrical component that implements electrical resistance as a circuit element. Resistors act to reduce current flow, and, at the same time, act to lower voltage levels within circuits. - Wikipedia | R41, R42 | 2
100K | 0.3Î© resistor A resistor is a passive two-terminal electrical component that implements electrical resistance as a circuit element. Resistors act to reduce current flow, and, at the same time, act to lower voltage levels within circuits. - Wikipedia | R43 | 1
RST | Momentary Switch (Pushbutton) - SPST Normally-open (NO) SPST momentary switches (buttons, pushbuttons). Variants PTH-12MM - 12mm square, through-hole Momentary Pushbutton Switch - 12mm Square (COM-09190) PTH-6.0MM, PTH-6.0MM-KIT - 6.0mm square, through-hole Mini Pushbutton Switch (COM-00097) KIT package intended for soldering kit's - only one side of pads' copper is exposed. PTH-RIGHT-ANGLE-KIT - Right-angle, through-hole Right Angle Tactile Button - Used on SparkFun BigTime Watch Kit SMD-12MM - 12mm square, surface-mount Tactile Button - SMD (12mm) (COM-12993) Used on SparkFun PicoBoard SMD-4.5MM - 4.5mm Square Trackball Switch Used on SparkFun Blackberry Trackballer Breakout SMD-4.6MMX2.8MM - 4.60mm x 2.80mm, surface mount Used on SparkFun SAMD21 Mini Breakout SMD-5.2MM, SMD-5.2-REDUNDANT - 5.2mm square, surface-mount Mini Pushbutton Switch - SMD (COM-08720) Used on Arduino Pro Mini REDUNDANT package connects both switch circuits together SMD-6.0X3.5MM - 6.0 x 3.5mm, surface mount Momentary Reset Switch SMD (COM-08229) SMD-6.2MM-TALL - 6.2mm square, surface mount Tactile Button - SMD (6mm) Used on SparkFun Digital Sandbox SMD-RIGHT-ANGLE - Right-angle, surface mount Used on SparkFun Block for IntelÂ® Edison - Arduino | S1 | 1
MOMENTARY-SWITCH-SPST-2-SMD-5.2MM | Momentary Switch (Pushbutton) - SPST - Two Circuits Normally-open (NO) SPST momentary switches (buttons, pushbuttons). Schematic symbol includes two switch circuits. Variants SMD-4.6MMX2.8MM - 4.60mm x 2.80mm Tactile Momentary Button Switch - Used on SparkFun SAMD21 Mini Breakout SMD-5.2MM - Mini Pushbutton Switch - SMD - Used on Arduino Pro Mini | S2, S3, S4, S5, S6, S7, S8, S9, S11 | 9
L | Momentary Switch (Pushbutton) - SPST Normally-open (NO) SPST momentary switches (buttons, pushbuttons). Variants PTH-12MM - 12mm square, through-hole Momentary Pushbutton Switch - 12mm Square (COM-09190) PTH-6.0MM, PTH-6.0MM-KIT - 6.0mm square, through-hole Mini Pushbutton Switch (COM-00097) KIT package intended for soldering kit's - only one side of pads' copper is exposed. PTH-RIGHT-ANGLE-KIT - Right-angle, through-hole Right Angle Tactile Button - Used on SparkFun BigTime Watch Kit SMD-12MM - 12mm square, surface-mount Tactile Button - SMD (12mm) (COM-12993) Used on SparkFun PicoBoard SMD-4.5MM - 4.5mm Square Trackball Switch Used on SparkFun Blackberry Trackballer Breakout SMD-4.6MMX2.8MM - 4.60mm x 2.80mm, surface mount Used on SparkFun SAMD21 Mini Breakout SMD-5.2MM, SMD-5.2-REDUNDANT - 5.2mm square, surface-mount Mini Pushbutton Switch - SMD (COM-08720) Used on Arduino Pro Mini REDUNDANT package connects both switch circuits together SMD-6.0X3.5MM - 6.0 x 3.5mm, surface mount Momentary Reset Switch SMD (COM-08229) SMD-6.2MM-TALL - 6.2mm square, surface mount Tactile Button - SMD (6mm) Used on SparkFun Digital Sandbox SMD-RIGHT-ANGLE - Right-angle, surface mount Used on SparkFun Block for IntelÂ® Edison - Arduino | S10 | 1
R | Momentary Switch (Pushbutton) - SPST Normally-open (NO) SPST momentary switches (buttons, pushbuttons). Variants PTH-12MM - 12mm square, through-hole Momentary Pushbutton Switch - 12mm Square (COM-09190) PTH-6.0MM, PTH-6.0MM-KIT - 6.0mm square, through-hole Mini Pushbutton Switch (COM-00097) KIT package intended for soldering kit's - only one side of pads' copper is exposed. PTH-RIGHT-ANGLE-KIT - Right-angle, through-hole Right Angle Tactile Button - Used on SparkFun BigTime Watch Kit SMD-12MM - 12mm square, surface-mount Tactile Button - SMD (12mm) (COM-12993) Used on SparkFun PicoBoard SMD-4.5MM - 4.5mm Square Trackball Switch Used on SparkFun Blackberry Trackballer Breakout SMD-4.6MMX2.8MM - 4.60mm x 2.80mm, surface mount Used on SparkFun SAMD21 Mini Breakout SMD-5.2MM, SMD-5.2-REDUNDANT - 5.2mm square, surface-mount Mini Pushbutton Switch - SMD (COM-08720) Used on Arduino Pro Mini REDUNDANT package connects both switch circuits together SMD-6.0X3.5MM - 6.0 x 3.5mm, surface mount Momentary Reset Switch SMD (COM-08229) SMD-6.2MM-TALL - 6.2mm square, surface mount Tactile Button - SMD (6mm) Used on SparkFun Digital Sandbox SMD-RIGHT-ANGLE - Right-angle, surface mount Used on SparkFun Block for IntelÂ® Edison - Arduino | S12 | 1
SWITCH-SPDT-SMD-RIGHT-ANGLE | Single Pole, Double Throw (SPDT) Switch Single-pole, double-throw (SPDT) switch. Variant Overview SMD-AYZ0202 Surface Mount DPDT Switch (COM-00597) Used on e.g. LilyPad Arduino USB - ATmega32U4 Board PTH-11.6X4.0MM SPDT Mini Power Switch (COM-00102) Used on e.g. SparkFun Simon Says - Through-Hole Soldering Kit (KIT-10547) PTH-11.6X4.0MM-KIT KIT version of SPDT Mini Power Switch - Simplifies soldering by removing tStop of switch pins - only one side can be soldered. PTH-11.6X4.0MM-LOCK LOCK version of SPDT Mini Power Switch - Offset pins hold switch in place for easier soldering. SMD-RIGHT-ANGLE Surface Mount Right Angle Switch (COM-10860) Used on e.g. SparkFun ESP8266 Thing | S13 | 1
600mA/40V | NPN transistor Current controlled devices typically used to amplify current or used as a switch. BC547 - COM-08928 (TO-92 45V 100mA) (1.Collector 2.Base 3.Emitter) 2N3904 - COM-00521 (TO-92 40V 200mA) (1.Emitter 2.Base 3.Collector) P2N2222A - COM-12852 (TO-92 40V 600mA) (1.Collector 2.Base 3.Emitter) | T1, T2, T3 | 3
TEST-POINT3 | SparkFun Test Points Bare copper test points for troubleshooting or In-Circuit-Testing. These are used by our Production team for verifying production board runs using pogo-pins on test beds. SparkFun Products: SparkFun LSM9DS1 Breakout SparkFun PSOC SparkFun Load Cell Amplifier | TP1, TP2, TP3, TP4 | 4
PCF8574 |  | U1 | 1
MIC5219 3.3V | V_REG MIC5219Standard 3.3V and 5V 500mA LDO voltage regulator in SOT-23 layout. Micrel part MIC5219. BP (by-pass) pin is used to lower output noise with 470pF cap, may be left open. | U2 | 1
LTC4054LES5-4.2#TRPBF | LTC4054L-4.2 - 150mA Standalone Linear Li-Ion Battery Charger in ThinSOT | U3 | 1
CH340G | A simple USB 2.0 to Serial IC. | U4 | 1
UDA1334ATS | UDA1334 I2C Audio DAC Power Supply: 2.4-3.6V Sample frequencies from 16-100kHz | U5 | 1
ESD0402 | None | U6, U7, U8 | 3
12Mhz | Crystals (Generic) These are passive quartz crystals, which can be used as a clock source for a microcontroller. Crystal's are two-terminal devices. They require external "load" capacitors to generate an oscillating signal. | Y1 | 1

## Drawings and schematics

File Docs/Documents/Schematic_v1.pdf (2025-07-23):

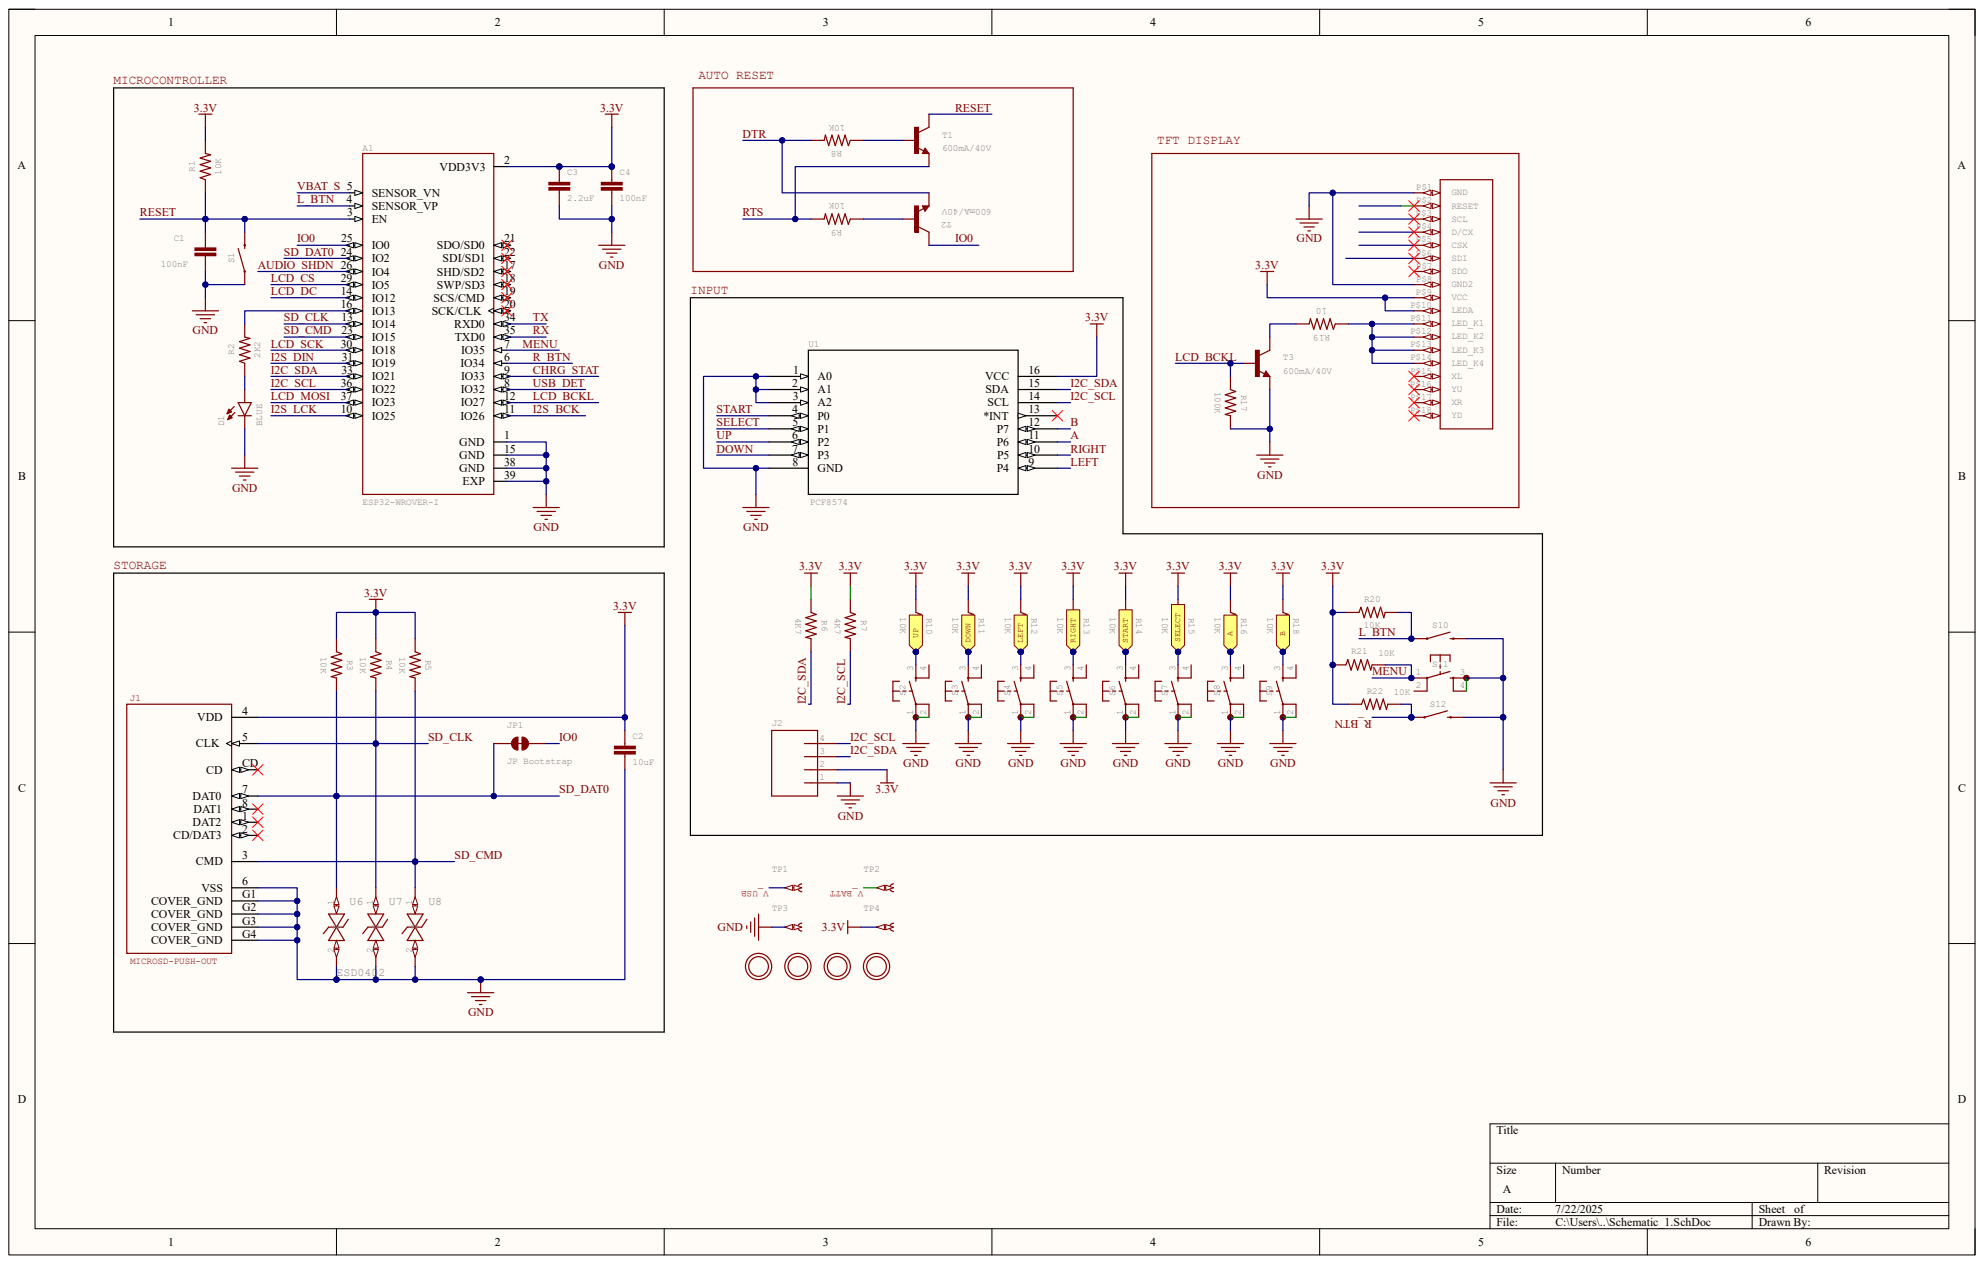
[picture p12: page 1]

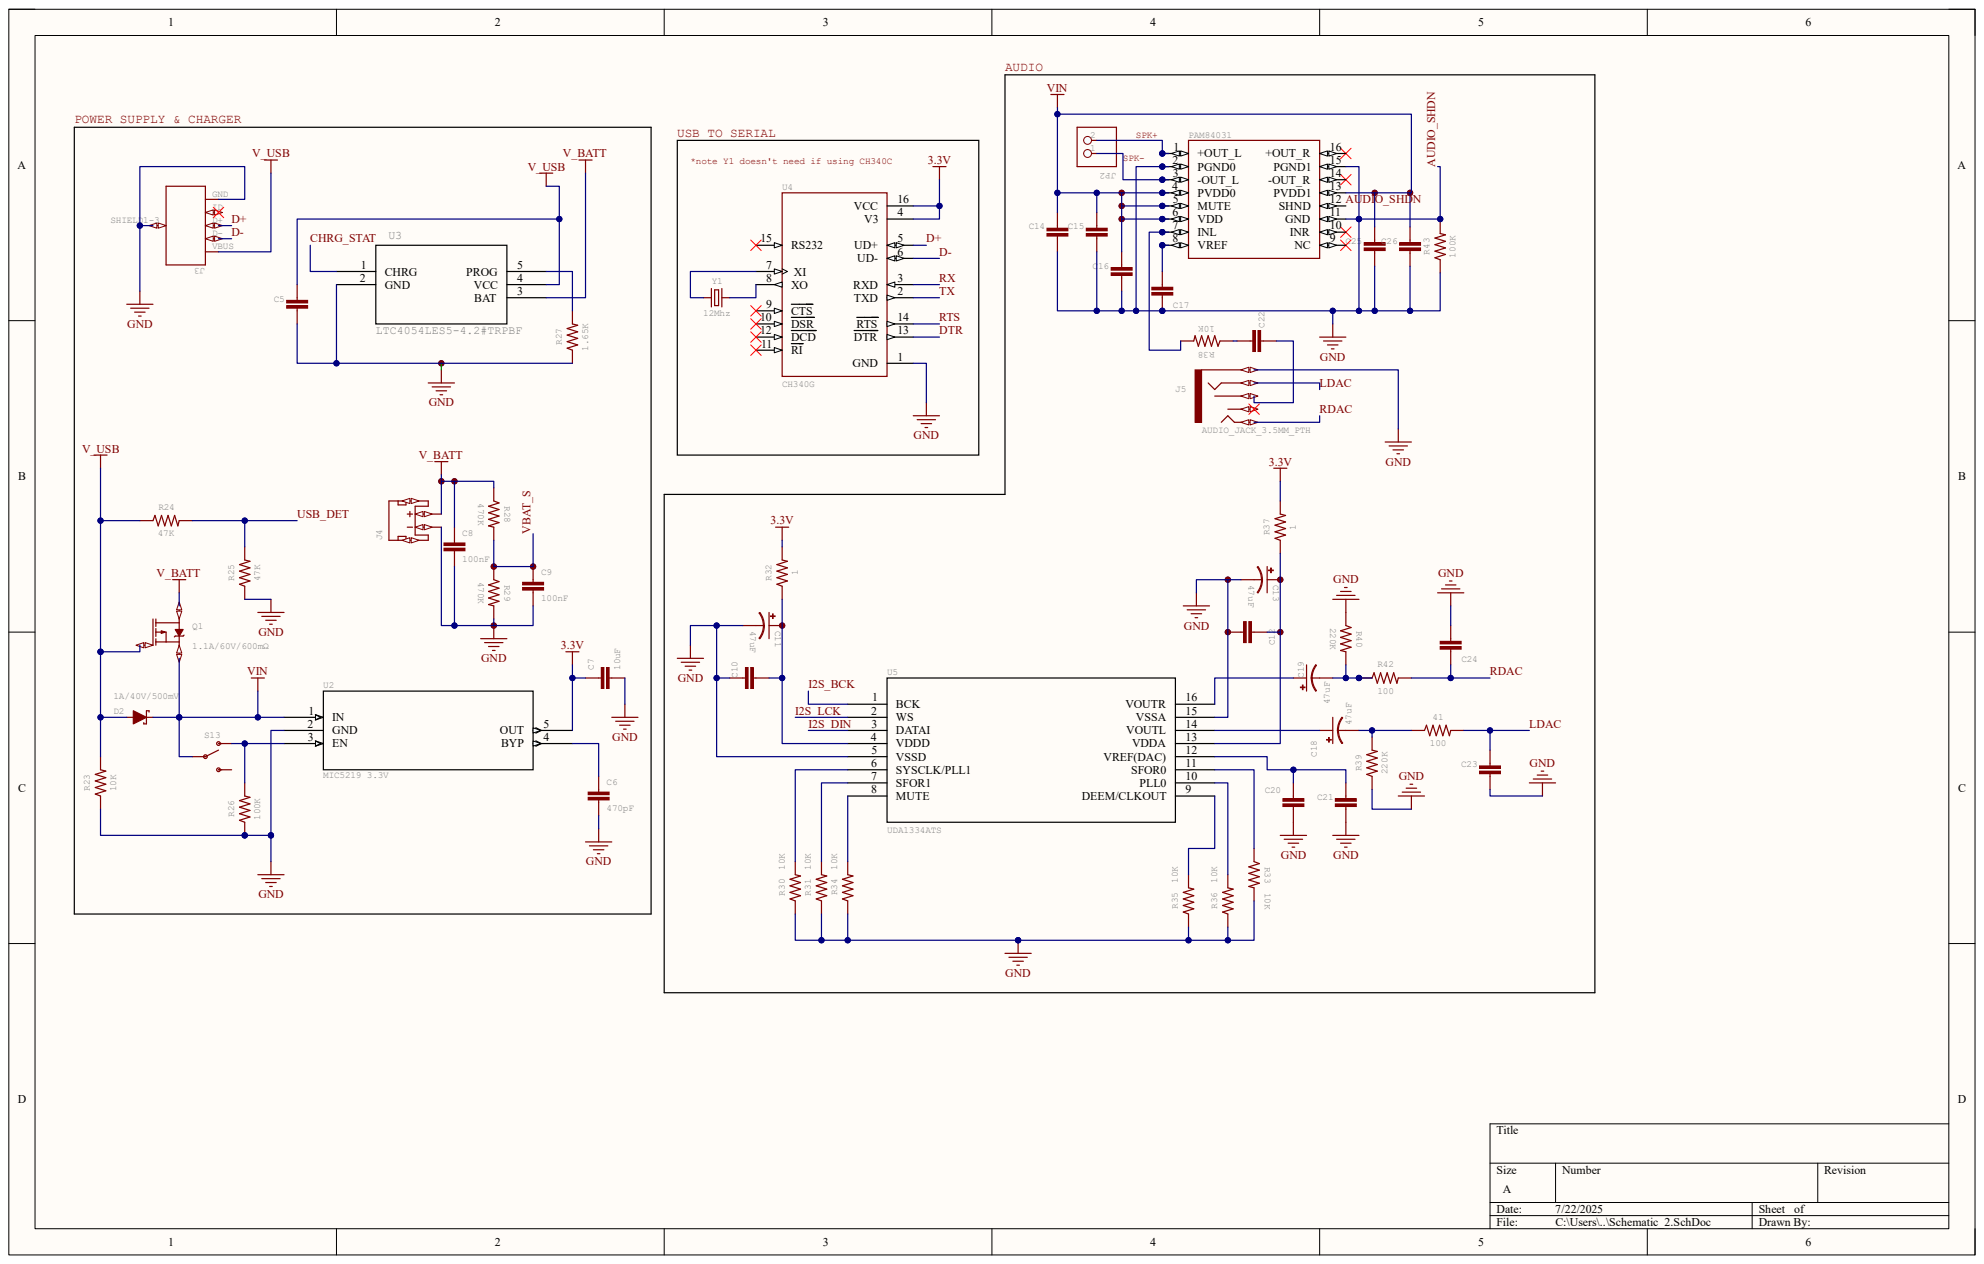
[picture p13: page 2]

*note Y1 doesn't need if using CH340C

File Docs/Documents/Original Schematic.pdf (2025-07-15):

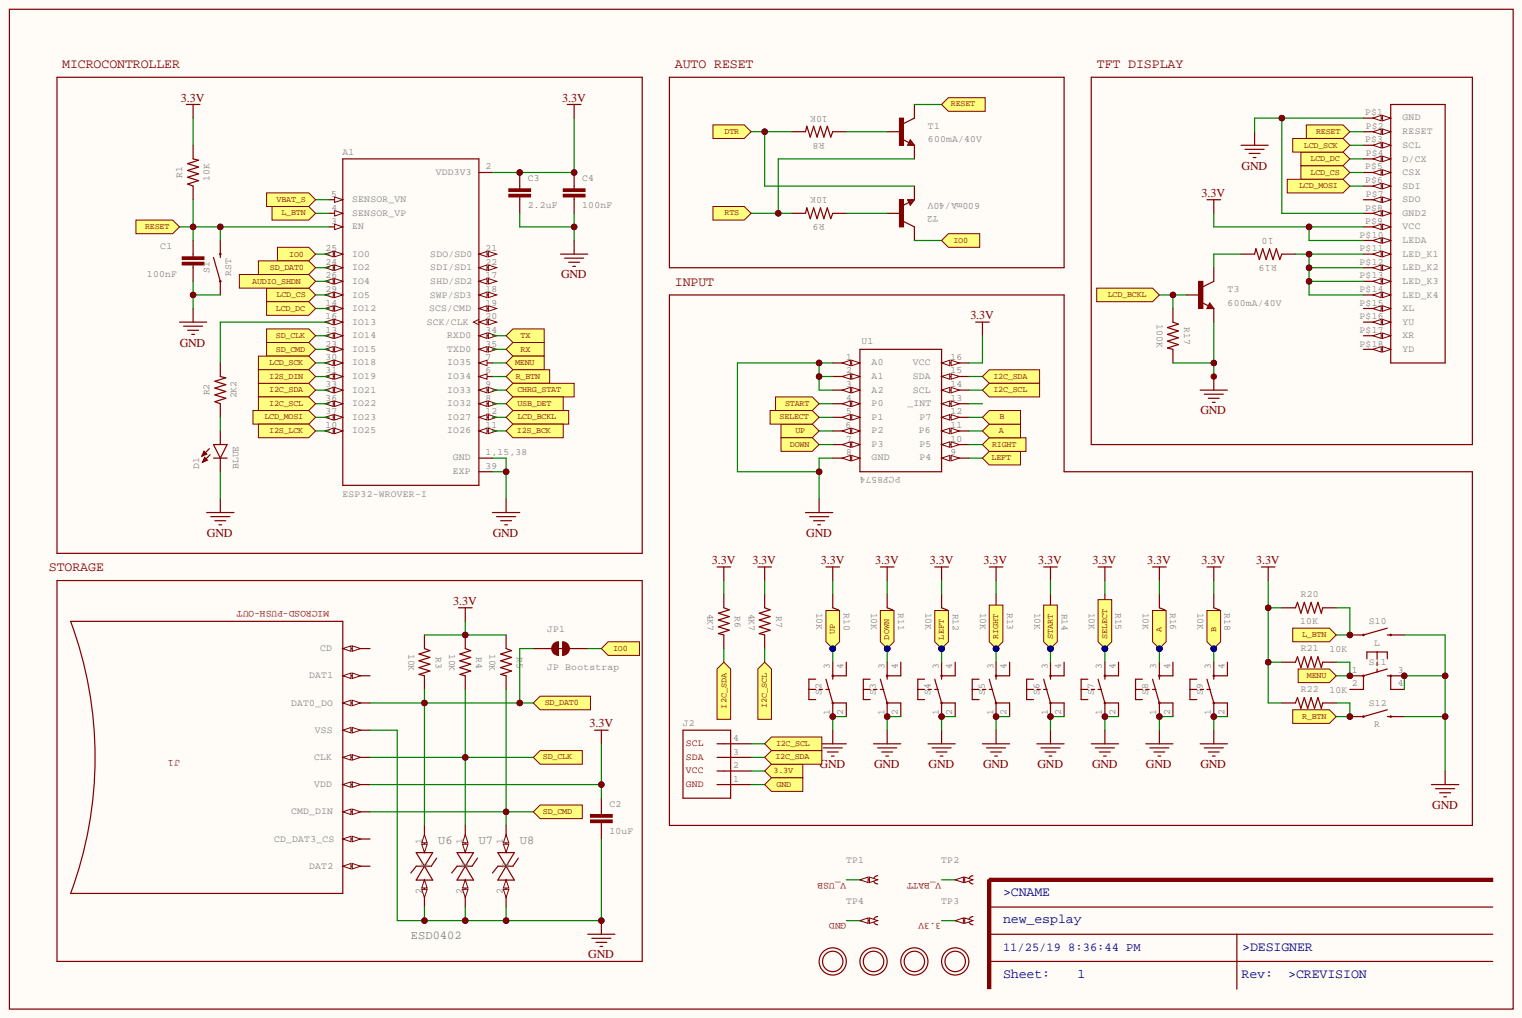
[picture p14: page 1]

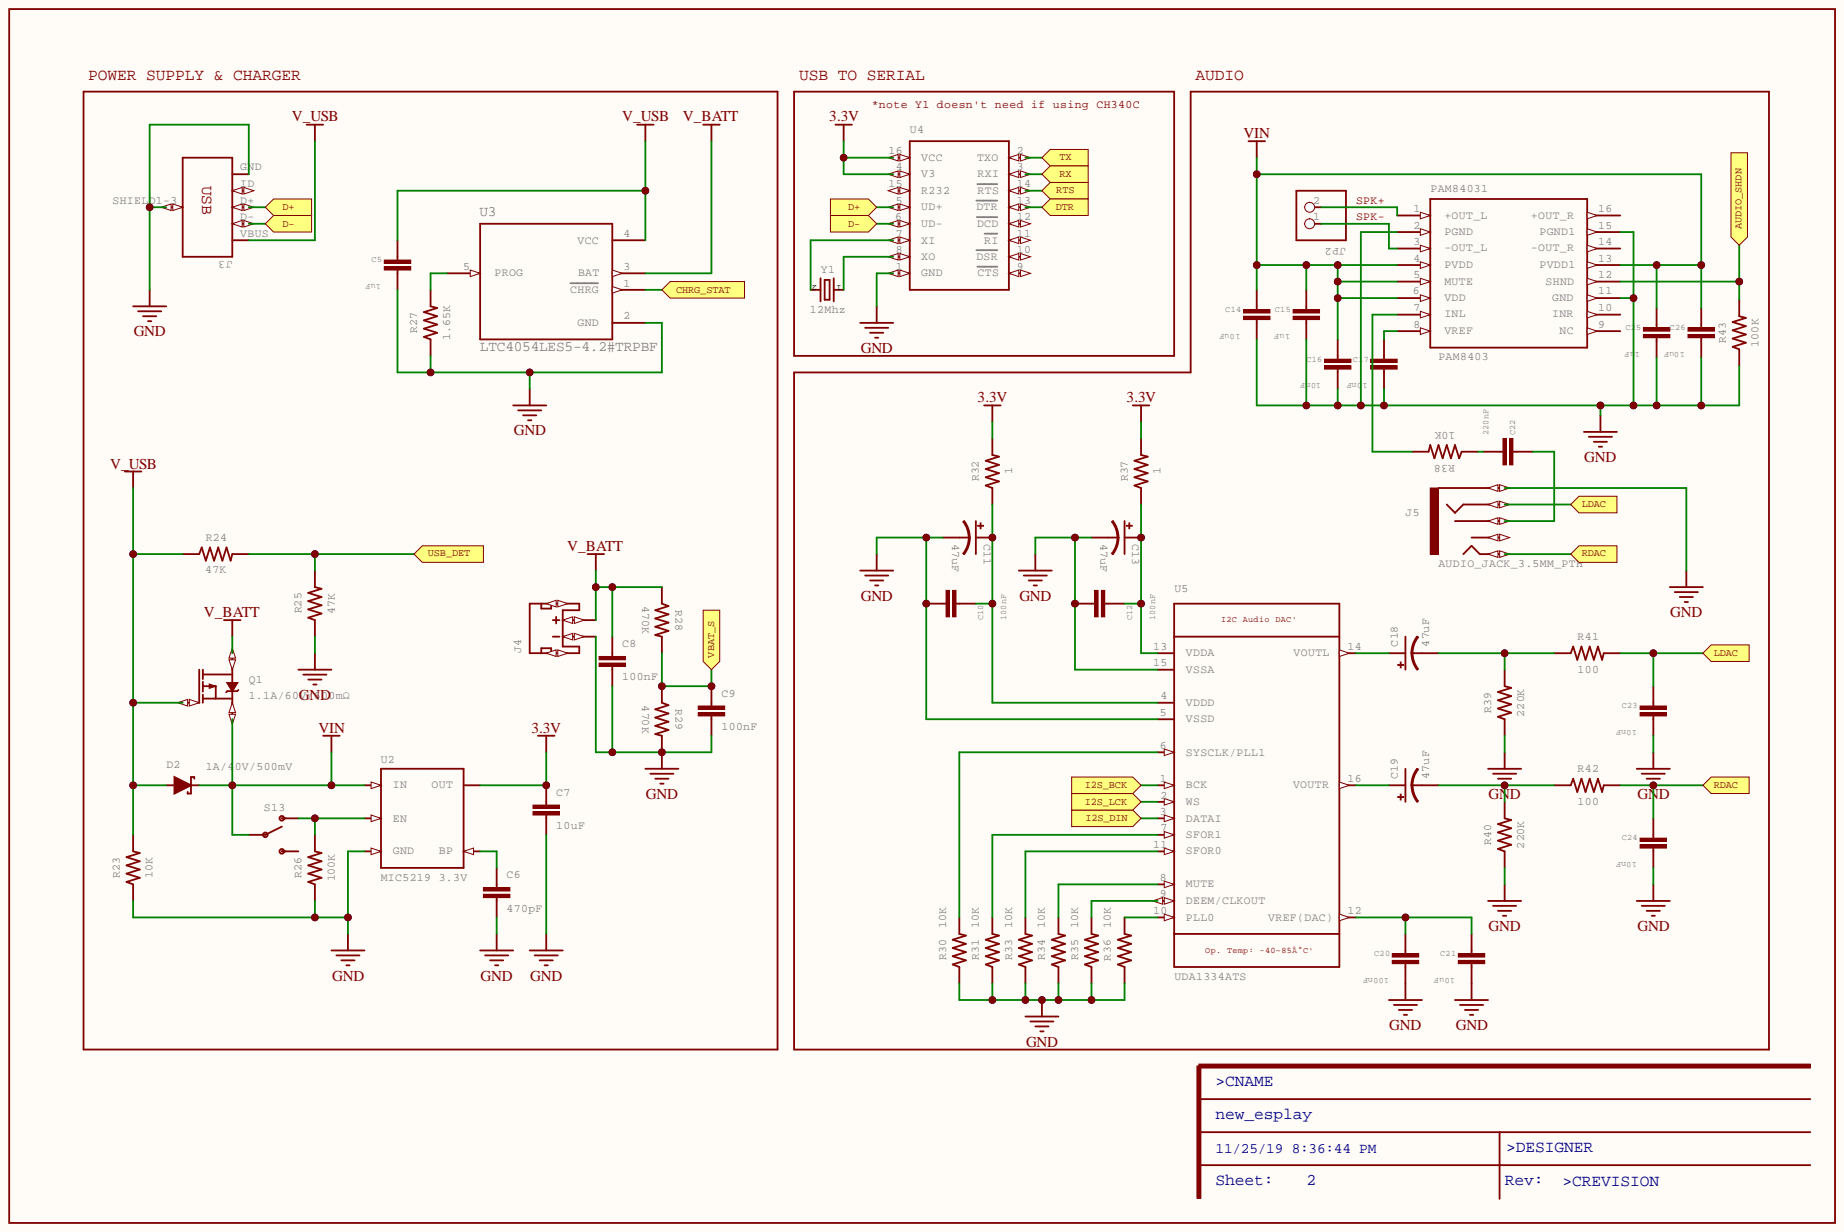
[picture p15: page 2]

5 | | 1 2
6 | 1 1 | 5 | C 2 6

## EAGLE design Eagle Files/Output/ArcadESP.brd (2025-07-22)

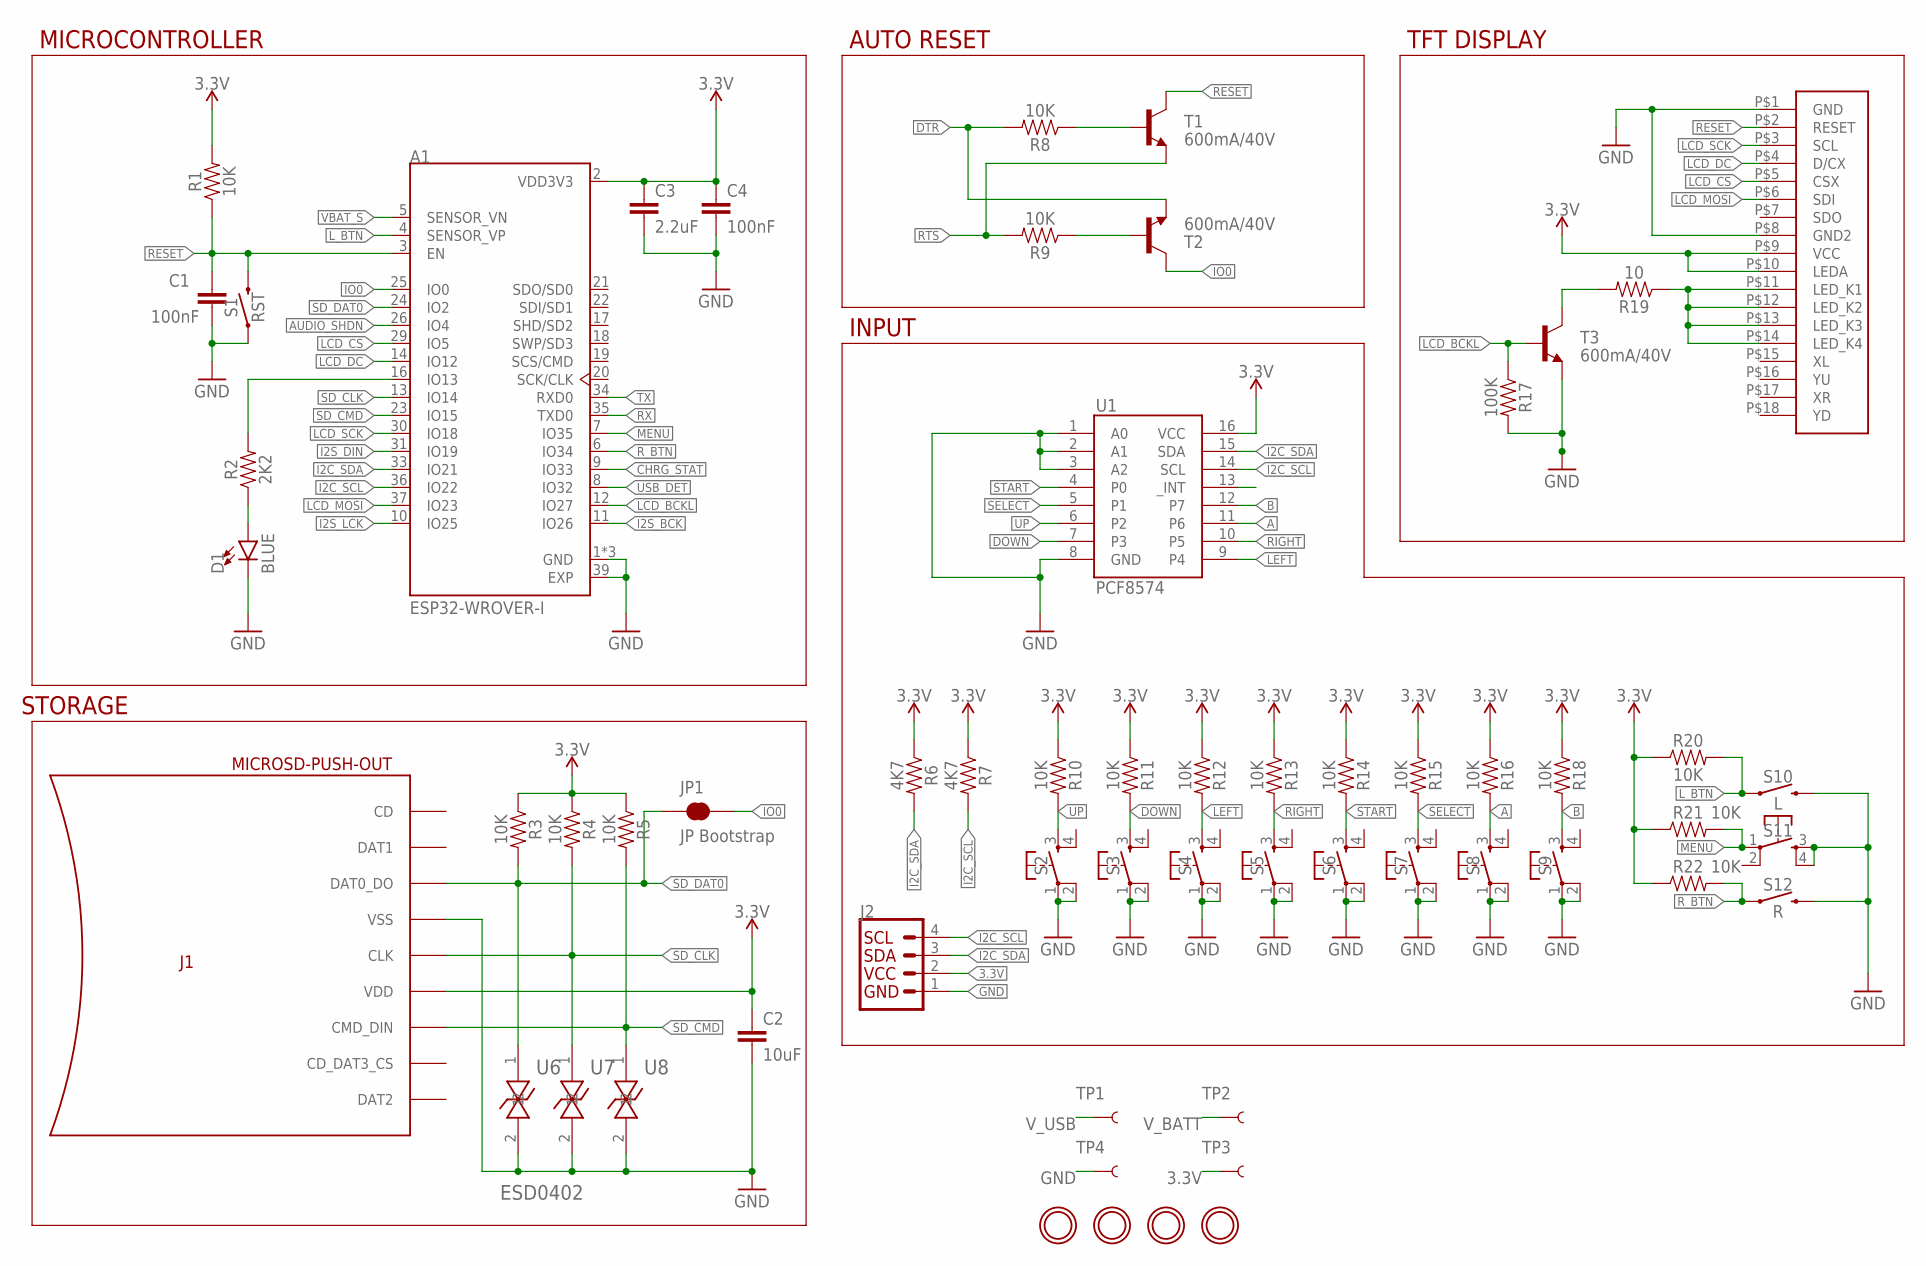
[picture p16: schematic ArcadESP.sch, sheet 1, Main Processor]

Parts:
A1: ESP32-WROVER-I; XCVR_ESP32-WROVER-I
C1, C4: 100nF; 0805
C2: 10uF; 0805
C3: 2.2uF; 0805
D1: BLUE; LED-0603
H1, H2, H3, H4: MICROBUILDER_MOUNTINGHOLE3.0THIN; MICROBUILDER_MOUNTINGHOLE_3.0_PLATEDTHIN
J1: MICROSD-PUSH-OUT
J2: QWIIC_CONNECTORJS-1MM; 1X04_1MM_RA
JP1: JP Bootstrap; SMT-JUMPER_2_NC_TRACE_NO-SILK
LCD1: ILI9341-2.4
R1, R3, R4, R5, R8, R9, R10, R11, R12, R13, R14, R15, R16, R18, R20, R21, R22: 10K; 0805
R2: 2K2; 0805
R6, R7: 4K7; 0805
R17: 100K; 0805
R19: 10; 0805
S1: RST; TACTILE_SWITCH_SMD_4.6X2.8MM
S2, S3, S4, S5, S6, S7, S8, S9, S11: MOMENTARY-SWITCH-SPST-2-SMD-5.2MM; TACTILE_SWITCH_SMD_5.2MM
S10: L; TACTILE_SWITCH_PTH_RIGHT_ANGLE_KIT
S12: R; TACTILE_SWITCH_PTH_RIGHT_ANGLE_KIT
T1, T2, T3: 600mA/40V; SOT23-3
TP1, TP2, TP3, TP4: TEST-POINT3; PAD.03X.03
U1: PCF8574; SO16
U6, U7, U8: ESD0402

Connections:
3.3V: A1.2 (VDD3V3), C2.1, C3.1, C4.1, J1.4 (VDD), J2.2, LCD1.P$9 (VCC), LCD1.P$10 (LEDA), R1.2, R3.1, R4.1, R5.1, R6.1, R7.1, R10.1, R11.1, R12.1, R13.1, R14.1, R15.1, R16.1, R18.1, R20.1, R21.1, R22.1, TP3.P$1, U1.16 (VCC); also elsewhere on the board
A: R16.2, S8.3, U1.11 (P6)
AUDIO_SHDN: A1.26 (IO4); also elsewhere on the board
B: R18.2, S9.3, U1.12 (P7)
CHRG_STAT: A1.9 (IO33); also elsewhere on the board
DOWN: R11.2, S3.3, U1.7 (P3)
DTR: R8.2, T2.2 (E); also elsewhere on the board
GND: A1.1 (GND), A1.15 (GND), A1.38 (GND), A1.39 (EXP), C1.2, C2.2, C3.2, C4.2, D1.C, J1.6 (VSS), J1.G1 (VSS), J1.G2 (VSS), J1.G3 (VSS), J1.G4 (VSS), J2.1, LCD1.P$1 (GND), LCD1.P$8 (GND2), R17.2, S1.1, S1.2 (1), S2.1, S2.2, S3.1, S3.2, S4.1, S4.2, S5.1, S5.2, S6.1, S6.2, S7.1, S7.2, S8.1, S8.2, S9.1, S9.2, S10.2, S11.3, S11.4, S12.2, T3.2 (E), TP4.P$1, U1.1 (A0), U1.2 (A1), U1.3 (A2), U1.8 (GND), U6.2, U7.2, U8.2; also elsewhere on the board
I2C_SCL: A1.36 (IO22), J2.4, R7.2, U1.14 (SCL)
I2C_SDA: A1.33 (IO21), J2.3, R6.2, U1.15 (SDA)
I2S_BCK: A1.11 (IO26); also elsewhere on the board
I2S_DIN: A1.31 (IO19); also elsewhere on the board
I2S_LCK: A1.10 (IO25); also elsewhere on the board
IO0: A1.25 (IO0), JP1.2, T2.3 (C)
LCD_BCKL: A1.12 (IO27), R17.1, T3.1 (B)
LCD_CS: A1.29 (IO5), LCD1.P$5 (CSX)
LCD_DC: A1.14 (IO12), LCD1.P$4 (D/CX)
LCD_MOSI: A1.37 (IO23), LCD1.P$6 (SDI)
LCD_SCK: A1.30 (IO18), LCD1.P$3 (SCL)
LEFT: R12.2, S4.3, U1.9 (P4)
L_BTN: A1.4 (SENSOR_VP), R20.2, S10.1
MENU: A1.7 (IO35), R21.2, S11.1
unnamed: A1.16 (IO13), R2.2
unnamed: D1.A, R2.1
unnamed: R19.2, T3.3 (C)
unnamed: LCD1.P$11 (LED_K1), LCD1.P$12 (LED_K2), LCD1.P$13 (LED_K3), LCD1.P$14 (LED_K4), R19.1
unnamed: R8.1, T1.1 (B)
unnamed: R9.1, T2.1 (B)
RESET: A1.3 (EN), C1.1, LCD1.P$2 (RESET), R1.1, S1.3 (2), S1.4 (2), T1.3 (C)
RIGHT: R13.2, S5.3, U1.10 (P5)
RTS: R9.2, T1.2 (E); also elsewhere on the board
RX: A1.35 (TXD0); also elsewhere on the board
R_BTN: A1.6 (IO34), R22.2, S12.1
SD_CLK: A1.13 (IO14), J1.5 (CLK), R4.2, U7.1
SD_CMD: A1.23 (IO15), J1.3 (CMD_DIN), R5.2, U8.1
SD_DAT0: A1.24 (IO2), J1.7 (DAT0_DO), JP1.1, R3.2, U6.1
SELECT: R15.2, S7.3, U1.5 (P1)
START: R14.2, S6.3, U1.4 (P0)
TX: A1.34 (RXD0); also elsewhere on the board
UP: R10.2, S2.3, U1.6 (P2)
USB_DET: A1.8 (IO32); also elsewhere on the board
VBAT_S: A1.5 (SENSOR_VN); also elsewhere on the board
V_BATT: TP2.P$1; also elsewhere on the board
V_USB: TP1.P$1; also elsewhere on the board

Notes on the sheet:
INPUT
TFT DISPLAY
AUTO RESET
STORAGE
MICROCONTROLLER

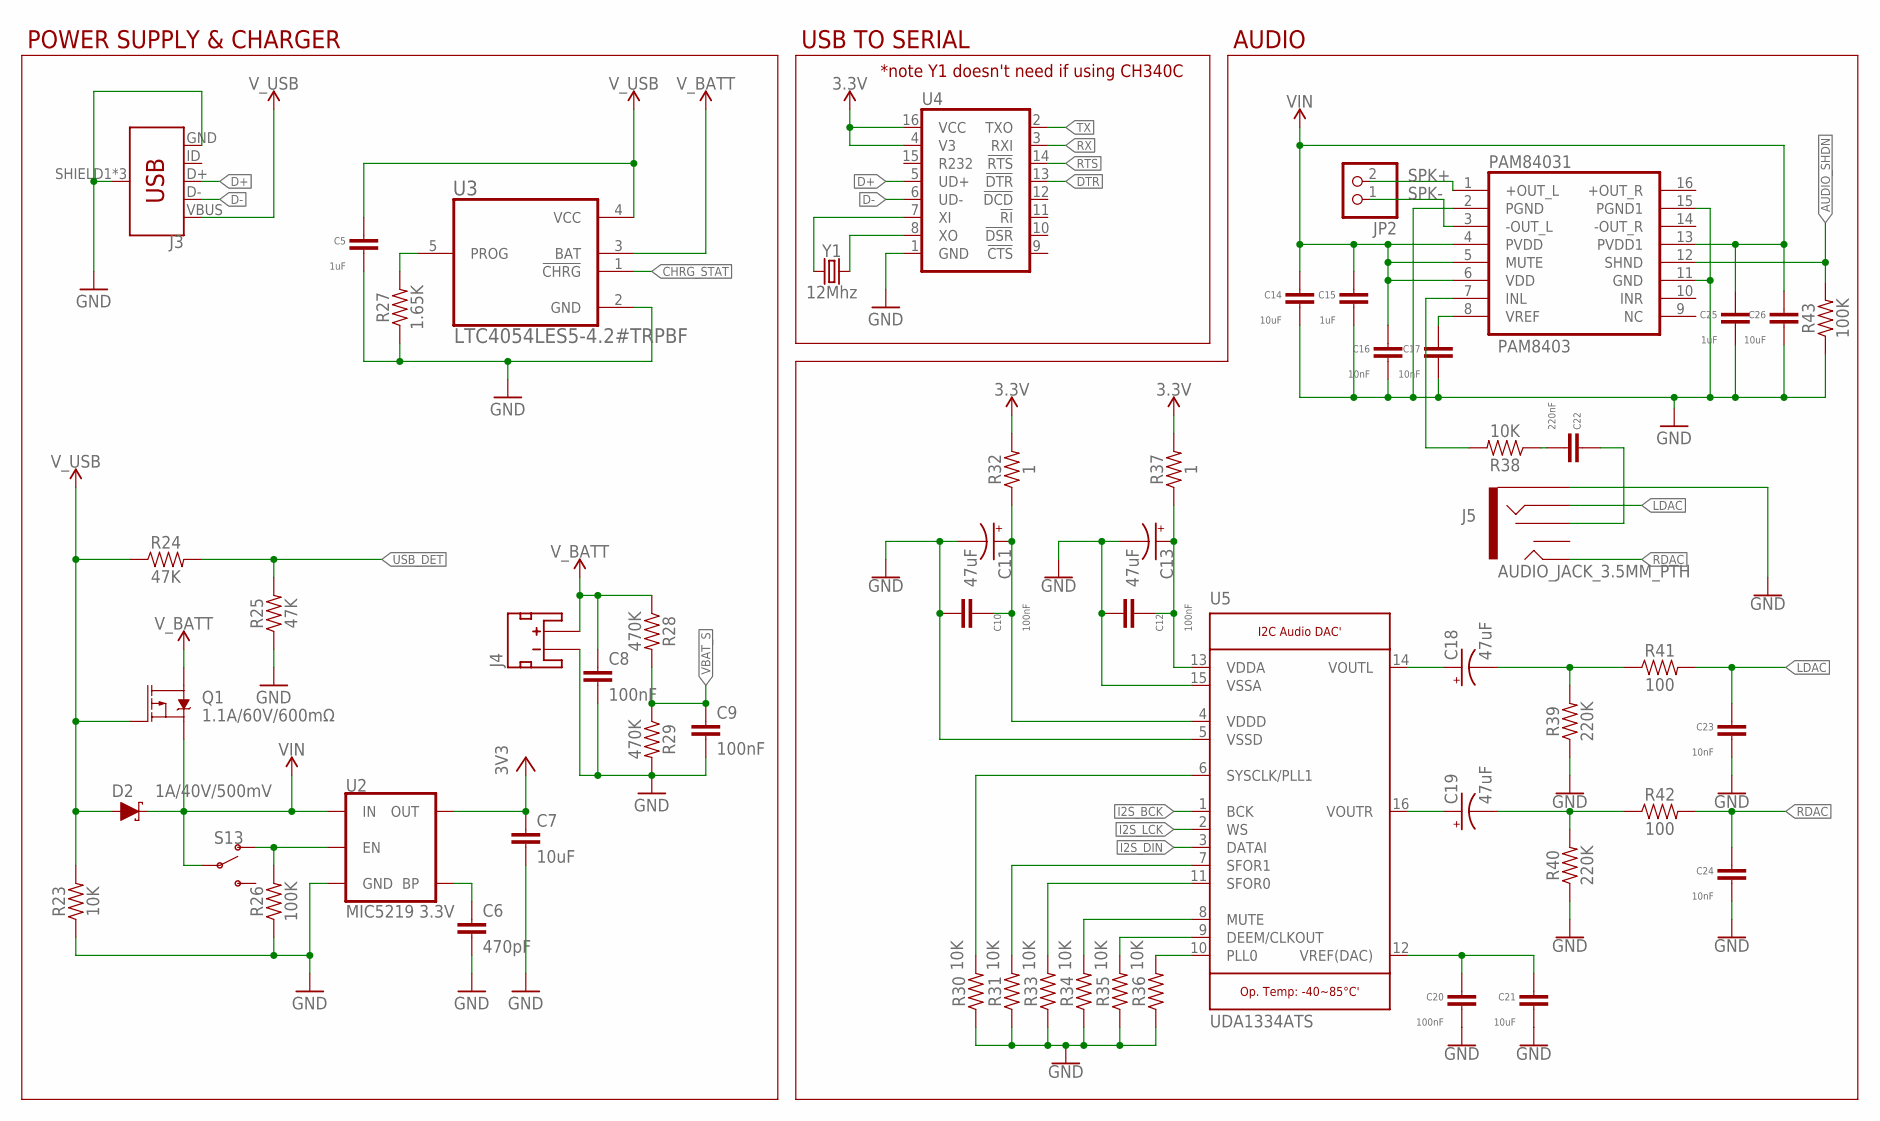
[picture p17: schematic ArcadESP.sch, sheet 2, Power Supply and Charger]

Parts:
C5, C15, C25: 1uF; 0805
C6: 470pF; 0805
C7, C14, C21, C26: 10uF; 0805
C8, C9, C10, C12, C20: 100nF; 0805
C11, C13, C18, C19: 47uF; EIA3528
C16, C17, C23, C24: 10nF; 0805
C22: 220nF; 0805
D2: 1A/40V/500mV; SMA-DIODE
J3: USB_MICRO-B_FEMALE-SMT; USB-B-MICRO-SMD
J4: JST_2MM_MALE; JST-2-SMD
J5: AUDIO_JACK_3.5MM_PTH; AUDIO-JACK
JP2: PINHD-1X2_2.00; 1X02M
PAM84031: PAM8403; SOP-16
Q1: 1.1A/60V/600mΩ; SOT23-3
R23, R30, R31, R33, R34, R35, R36, R38: 10K; 0805
R24, R25: 47K; 0805
R26, R43: 100K; 0805
R27: 1.65K; 0805
R28, R29: 470K; 0805
R32, R37: 1; 0805
R39, R40: 220K; 0805
R41, R42: 100; 0805
S13: SWITCH-SPDT-SMD-RIGHT-ANGLE; SWITCH_SPST_SMD_A
U2: MIC5219 3.3V; SOT23-5
U3: LTC4054LES5-4.2#TRPBF; SOT95P280X100-5N
U4: CH340G; SO016
U5: UDA1334ATS; MICROBUILDER_SSOP16_4.4MM
Y1: 12Mhz; CRYSTAL-SMD-5X3.2-4PAD

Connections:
3.3V: C7.1, R32.2, R37.2, U2.5 (OUT), U4.4 (V3), U4.16 (VCC); also elsewhere on the board
AUDIO_SHDN: PAM84031.12 (SHND), R43.2; also elsewhere on the board
CHRG_STAT: U3.1 (!CHRG); also elsewhere on the board
D+: J3.D+, U4.5 (UD+)
D-: J3.D-, U4.6 (UD-)
DTR: U4.13 (!DTR); also elsewhere on the board
GND: C5.1, C6.2, C7.2, C8.2, C9.2, C10.1, C11.C (-), C12.1, C13.C (-), C14.1, C15.1, C16.1, C17.1, C20.1, C21.1, C23.1, C24.1, C25.1, C26.1, J3.GND, J3.SHIELD1 (SHIELD), J3.SHIELD2 (SHIELD), J3.SHIELD3 (SHIELD), J4.1 (-), J5.SLEEVE, PAM84031.2 (PGND), PAM84031.11 (GND), PAM84031.15 (PGND1), R23.1, R25.1, R26.1, R27.1, R29.2, R30.1, R31.1, R33.1, R34.1, R35.1, R36.1, R39.1, R40.1, R43.1, U2.2 (GND), U3.2 (GND), U4.1 (GND), U5.5 (VSSD), U5.15 (VSSA); also elsewhere on the board
I2S_BCK: U5.1 (BCK); also elsewhere on the board
I2S_DIN: U5.3 (DATAI); also elsewhere on the board
I2S_LCK: U5.2 (WS); also elsewhere on the board
LDAC: C23.2, J5.RING, R41.2
unnamed: R27.2, U3.5 (PROG)
unnamed: U4.7 (XI), Y1.3 (2)
unnamed: C18.A (+), U5.14 (VOUTL)
unnamed: U4.8 (XO), Y1.1
unnamed: R26.2, S13.1 (O), U2.3 (EN)
unnamed: C6.1, U2.4 (BP)
unnamed: C19.A (+), U5.16 (VOUTR)
unnamed: C17.2, PAM84031.8 (VREF)
unnamed: PAM84031.7 (INL), R38.2
unnamed: C18.C (-), R39.2, R41.1
unnamed: C19.C (-), R40.2, R42.1
unnamed: C12.2, C13.A (+), R37.1, U5.13 (VDDA)
unnamed: C20.2, C21.2, U5.12 (VREF(DAC))
unnamed: C10.2, C11.A (+), R32.1, U5.4 (VDDD)
unnamed: C22.1, R38.1
unnamed: R30.2, U5.6 (SYSCLK/PLL1)
unnamed: R31.2, U5.7 (SFOR1)
unnamed: R33.2, U5.11 (SFOR0)
unnamed: R34.2, U5.8 (MUTE)
unnamed: R35.2, U5.9 (DEEM/CLKOUT)
unnamed: R36.2, U5.10 (PLL0)
unnamed: C22.2, J5.RSH
RDAC: C24.2, J5.TIP, R42.2
RTS: U4.14 (!RTS); also elsewhere on the board
RX: U4.3 (RXI); also elsewhere on the board
SPK+: JP2.2, PAM84031.1 (+OUT_L)
SPK-: JP2.1, PAM84031.3 (-OUT_L)
TX: U4.2 (TXO); also elsewhere on the board
USB_DET: R24.2, R25.2; also elsewhere on the board
VBAT_S: C9.1, R28.2, R29.1; also elsewhere on the board
VIN: C14.2, C15.2, C16.2, C25.2, C26.2, D2.C, PAM84031.4 (PVDD), PAM84031.5 (MUTE), PAM84031.6 (VDD), PAM84031.13 (PVDD1), Q1.2 (S), S13.2, U2.1 (IN)
V_BATT: C8.1, J4.2 (+), Q1.3 (D), R28.1, U3.3 (BAT); also elsewhere on the board
V_USB: C5.2, D2.A, J3.VBUS, Q1.1 (G), R23.2, R24.1, U3.4 (VCC); also elsewhere on the board

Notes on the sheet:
POWER SUPPLY & CHARGER
USB TO SERIAL
AUDIO
*note Y1 doesn't need if using CH340C

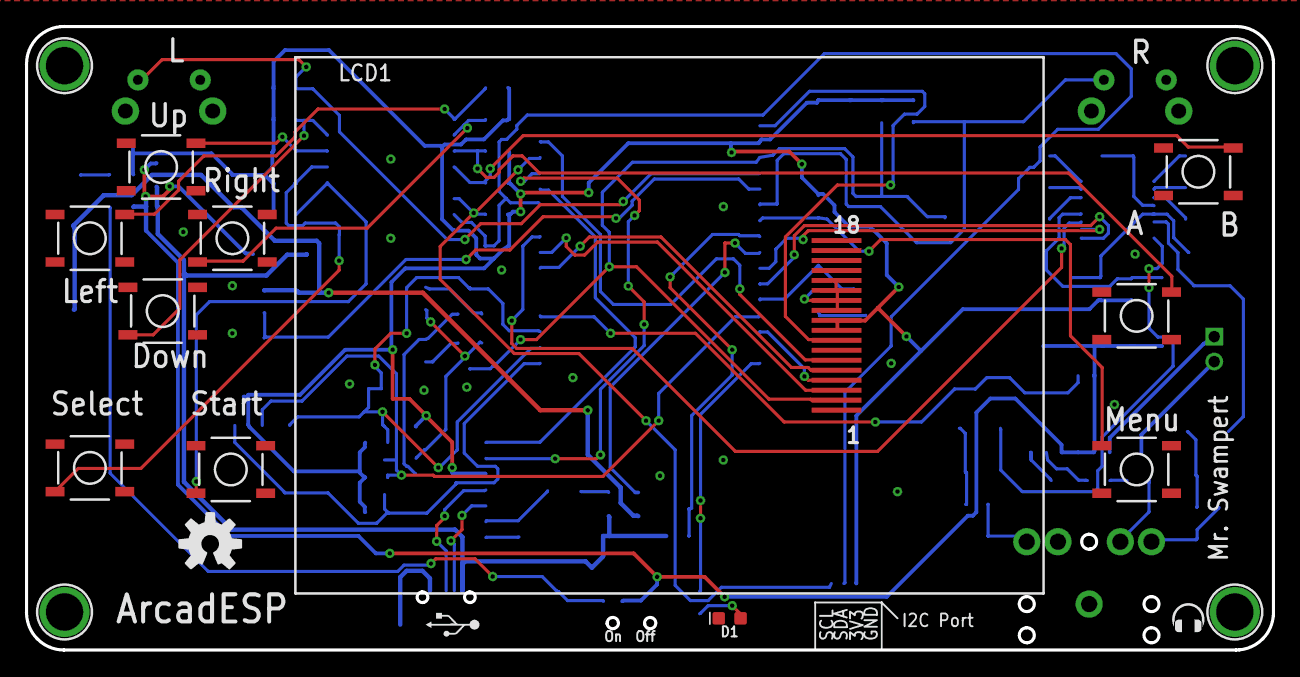
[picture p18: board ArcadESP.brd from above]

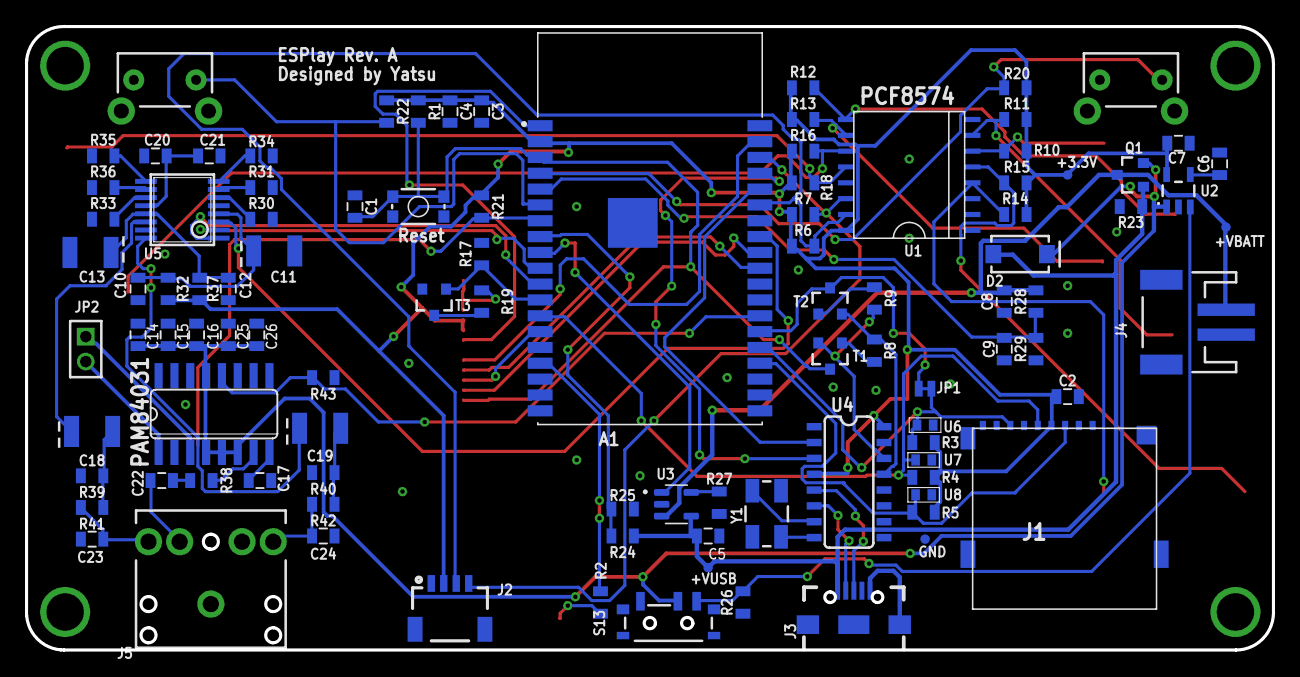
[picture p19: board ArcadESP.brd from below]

Board: 2 copper layers, 100.0 x 50.0 mm, 118 parts (100 on the bottom side), 73 nets.

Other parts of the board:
U$1: OSHW-LOGO-M
U$2: USB_LOGO
U$3: HEADPHONE_LOGO

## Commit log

2025-07-14 Add Report Components
    Se añade un informe analizado con IA de algunos cambios al proyecto original
2025-07-14 Add BOM
    Se añade la lista de los materiales con sus enlaces respectivos
    [new_esplay - Copy.xlsx]
2025-07-15 Upload Files
    Se añaden nuevos documentos, incluido el BOM el cual le hace falta buscar unos componentes
    [BOM.xlsx]
2025-07-15 Update Upload
    Se añade imagen de la PCB en 3D
2025-07-15 Upload BOM
    Se actualiza el BOM con el subtotal de todo, pero siguen faltando componentes por buscar
    [BOM.xlsx]
2025-07-22 Upload Files
    Add New Files
    [BOM.xlsx]
2025-07-22 Add Eagle Folder
    Add Eagle Folder with Output Files
    [ArcadESP.brd, ArcadESP.sch, PnP_new_esplay_back.csv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]
2025-07-22 Update README.md
    Update Power Budget
2025-07-22 Add New Files
    Add Power Budget and Block Diagram
2025-07-23 Add schematics
    Add old and new version
2025-07-23 Update schematic
    Add new version v2
2025-07-23 Add schematic
    Add new version v3
2025-07-23 Update README.md
    Replace schematic pag 2
2025-07-24 Add Altium Files
    Add Altium Files
    [2D Components_v1.SchLib, 3D Components_v1.PcbLib, ArcadESP v1.PrjPcb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]

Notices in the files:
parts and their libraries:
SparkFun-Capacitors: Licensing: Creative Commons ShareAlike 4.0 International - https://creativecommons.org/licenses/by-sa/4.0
